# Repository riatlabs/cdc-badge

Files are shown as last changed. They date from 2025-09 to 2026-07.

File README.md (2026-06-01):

# CDC Badge

Electronic hacker badge for the [Critical Decentralization Cluster](https://decentral.community),
featuring the [TROPIC01](https://github.com/tropicsquare/tropic01) secure
element with an [ESP32-S3](https://www.espressif.com/en/products/socs/esp32-s3/) microcontroller.

Meant to be used for workshops and prototyping. It can also be worn as a mobile
badge. Features an e-paper display with frontlight, a JST connector for
single-cell LiPo batteries and a 12-button keypad.

Repository contents:
- [cdc-badge](/cdc-badge) - KiCAD project with schematics and PCB
  layout.
- [cases](/cases) - 3D printable cases.
- [docs](/docs) - Detailed documentation including datasheets and design
  decisions.
- [utils](/utils) - Miscellaneous scripts.

## Firmware
- [cdc-badge-os](https://github.com/krim404/cdc-badge-os) - Fully featured,
  modular and extensible firmware built with PlatformIO and ESP-IDF. Uses the
  TROPIC01 to build an hardware-backed key vault with support for FIDO2,
  TOTP, SSH/GPG keys and regular passwords. Also does badge functionally:
  nametag and vCard sharing.
- [xmr-cdc-badge](https://codeberg.org/telliandev/xmr-cdc-badge) - A Monero
  hardware wallet running on the CDC Badge. Built with PlatformIO.
- [cdc-badge-esphome](https://github.com/gretel/cdc-badge-esphome) - Port of
  [ESPHome](https://esphome.io). Turns the badge into a smart home device
  connected to [Home Assistant](https://www.home-assistant.io).
- [rugart](https://gitlab.com/roosemberth/rugart) - Standards-compliant PIV
  smartcard over USB CCID developed in Rust.
- [cdc-badge-nametag](https://github.com/riatlabs/cdc-badge-nametag) - Simple
  nametag with frontlight control. Built with PlatformIO.

In order to safely operate the hardware, firmware developers should take into
account all the points in the [firmware checklist](/docs/firmware-checklist.md).

The [cdc-badge-qc-firmware](https://github.com/riatlabs/cdc-badge-qc-firmware)
repo contains test batteries which make sure the hardware is working as
expected.

### Flashing
Options:
1. Via USB.
2. Via UART. TX and RX are broken out to the Raspberry Pi header on pins 8 and 10.
   The reset and flash buttons are physically placed near the ESP32.

When flashing a badge for the first time over USB you may need to press the
classic flash + reset button sequence in order to get it out of a boot loop.

## Example applications
- Interactive name tag
- Social networking games
- Monero hardware wallet
- Reticulum node with secure key storage and ECC acceleration
- FIDO2 keystore
- Pager and short message chatting
- Local AI with the Sipeed M1 HAT: e.g. voice activated control

## Expansions
The badge has 3 expansion ports:
- Raspberry Pi [40 pin GPIO header](https://pinout.xyz) ready to take any [HAT or pHAT](https://pinout.xyz/boards)
- [SAO](https://badge.team/docs/standards/sao/) ~~Shitty~~ Standardized Add-On
  port to connect small PCBs with blinky LEDs, speakers, and other bling.
- [Grove](https://wiki.seeedstudio.com/Grove_System) compatible connector to
  interface with any Grove sensor or network module. Has selectable output
  voltage (3.3 V or 5 V).

The [Grove AI HAT for Edge Computing](https://wiki.seeedstudio.com/Grove_AI_HAT_for_Edge_Computing/)
is a good pairing for more demanding applications. It is based on the [Kendryte
K210 SoC](https://www.kendryte.com/en/proDetail/210) which has 2 RISC-V 64 bit
cores and many custom accelerators (AI/NPU/CNN, audio, FFT, AES, SHA256).

### SPI to internal devices
It is possible to interface via SPI from the Raspberry Pi header to the e-paper
display and the TROPIC01. There are 2 mechanical sliding switches which you can
use to connect pin 24 and pin 26 to the chip select (CS) of these devices.

The auxiliary signals from the e-paper display (DC, RST, BUSY) are available on
pins 29, 31 and 36. The interrupt signal from TROPIC01 is available on pin 37.

This allows an external microcontroller, for instance the Sipeed M1, to display
graphics on the screen and use the secure element.

### Buttons
Besides the reset and flash buttons (directly connected to the ESP32) there are
12 buttons connected to the TCA9535 IO Expader. These can be access through I²C
and used as keypad for user input.

These is also a button (PW ON / RESET) directly connected to the BQ25895
charging IC. It has fixed functionality:
- If the BQ25895 is set to shipping mode (output power disabled), pressing the
  PW ON / RESET button for 2s disables the shipping mode and allows power to flow to the
  ESP32.
- During battery-powered operation (i.e. no charger is plugged in), pressing the
  PW ON / RESET for 12s forces a full power reset.

## Power characteristics

### Maximum
The maximum total current that can be drawn out of the power bus is:
- 3.3 V: 2 A
- 5 V: 2.5 A

Take into account that all badge components (ESP32, TROPIC01, display, etc.)
draw their power from the 3.3 V bus.

### Minimum
All onboard ICs have very low quiescent currents, under 40 μA. Even the ESP32-S3
can go as low as 8 μA in it's deep sleep mode (240 μA in light sleep mode). The
major exception is the TROPIC01 which draws 945 μA in sleep mode.

If a use case requires the lowest power usage possible, the exposed copper trace
connecting VCC to the TROPIC01 should be cut. It can later be reconnected with a
0 Ω resistor or a wire (0603 pads available). This exposed trace can also be
used to do power glitch testing on the TROPIC01.

On most use cases the sleep mode power usage of the TROPIC01 will be
insignificant though. For instance, while listening for WiFi transmissions, the
ESP32-S3 draws 95 mA. The TROPIC01 sleep mode current is just 1% of this.

## Manufacturing
There's a [Makefile](/cdc-badge/Makefile) to generate the fabrication
outputs.

To run it you need the following dependencies installed in your system:
- A Make implementation, e.g. [GNU Make](https://www.gnu.org/software/make/),
  packaged in most distros as `make`.
- [KiKit](https://yaqwsx.github.io/KiKit/latest/installation/intro/),
  packaged [in Arch as python-kikit](https://archlinux.org/packages/extra/any/python-kikit/)
  and [in NixOs as kikit](https://search.nixos.org/packages?show=kikit).

Running `make` in the `cdc-badge` directory will output the fabrication files
into the `production/` directory.

So far outputs are created just for JLCPCB, but [other manufacturers can be
easily supported](https://yaqwsx.github.io/KiKit/latest/fabrication/intro/#currently-supported).

### Panelization
Panelization is an intermediate step in the fabrication outputs generation
detailed above, but it can be run independently. `make panel` generates a 1x2
panel of the PCB into `production/panel.kicad_pcb`. This panel is the preferred
way to send the badge for fabrication. It reduces costs while preserving a rigid
structure.

## Further documentation
Please check:
- the [docs](/docs/) directory;
- the [KiCad schematics](/cdc-badge/cdc-badge.kicad_sch) (available as PDF in
  the [releases](https://github.com/riatlabs/cdc-badge/releases));

## Acknowledgments
We would like to thank:

* **ceetee**, for all the in-depth reviews, and for making us aware that we are
guiding electromagnetic waves through the dielectric and not moving water
through pipes.

* **krim**, for the tireless firmware development.

## License and authorship
Copyright © 2025-2026 RIAT Institute

Licensed under [CERN Open Hardware Licence Version 2 - Permissive](/LICENSE).

Third-party resources' authorship and license information in [AUTHORS.md](/AUTHORS.md)

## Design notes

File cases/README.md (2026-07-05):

# CDC Badge Cases

## ari
Two-part case secured by screws. Exposes screen, USB-C port, Rasp Pi header and
Grove connector. Covers SAO port.

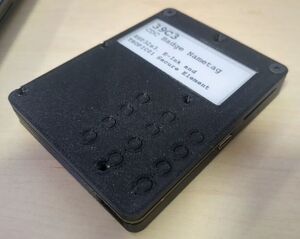
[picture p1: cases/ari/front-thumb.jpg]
front piece of ari's case

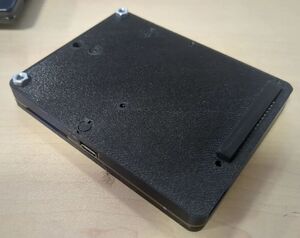
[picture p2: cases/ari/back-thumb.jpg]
back piece of ari's case


Requires:
- 2x M4 nuts
- 2x M4x15 countersunk screws
- 4x M2x15 countersunk screws (not tested, but M3 is definitely too large)
- 4x M2 nuts

Designed for printing with 2 walls with 0.6mm nozzle; 3 walls with 0.4mm nozzle
should work fine as well.

Links: [https://www.printables.com/model/1543553-cdc-badge-2-part-case](https://www.printables.com/model/1543553-cdc-badge-2-part-casel)\
Original (for CDC Badge v1.0) by [ari](https://is-a.cat/@ar).\
Adapted to v1.1 by [bobotronic](https://github.com/bobotronic).\
Licensed under [CC BY 4.0](http://creativecommons.org/licenses/by/4.0/).

## ct
Back-only case secured by clips. Exposes USB-C and SAO ports. Covers battery,
Rasp Pi header and Grove connector.

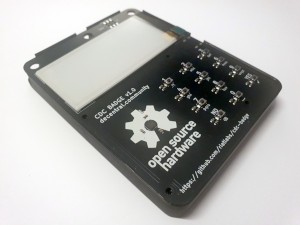
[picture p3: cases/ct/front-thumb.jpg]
front view of ct's case

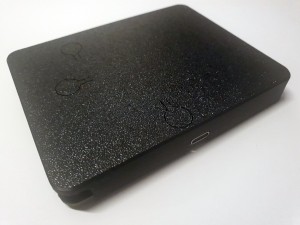
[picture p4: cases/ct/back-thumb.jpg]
back view of ct's case


Fit is close, make sure your printer can meet tolerances or add an outer wall
offset. Printing in PETG is recommended for semi flexible retention clips. PLA
works, but clips can break if you are not careful.

By [ceetee](https://github.com/its-me-ct).\
Licensed under [CERN Open Hardware Licence Version 2 - Permissive](../LICENSE).

## header-cap
A simple protective cover that fits into the Rasp Pi header and keeps the pins
from rubbing on your clothes when wearing the badge.

Two versions are available: a simple one and a beveled one. Which one fits best
depends on the particular filament that you print with. Try both versions.

By [bobotronic](https://github.com/bobotronic).\
Licensed under [CERN Open Hardware Licence Version 2 - Permissive](../LICENSE).

## Button height difference
The CDC Badge v1.0, the first production version, used [TS-1088-AR02016](https://snapeda.s3.amazonaws.com/datasheets/2304140030_XUNPU-TS-1088-AR02016_C720477.pdf)
tactile push buttons, which were found to be a bit hard to press. v1.1 and later
replaced them for [ALPS TS114516025 clones](https://www.lcsc.com/datasheet/C22375312.pdf).
These are 0.5 mm taller and thus required adjustments to the cases.

To cater for this height difference you will find the cases available in two
versions: `v1.0` and `v1.1`.

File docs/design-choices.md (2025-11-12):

# Design Choices

## Microcontroller Selection
Opted for the ESP32-S3 because of:
- USB On-The-Go (OTG) support (can act as host or peripheral).
- Onboard Bluetooth and WiFi.
- Detailed documentation available.
- Mature support in many programming languages and IDEs.
- High performance (dual-core Xtensa).
- High GPIO count.

Alternatives like the ESP32-C6 and the ESP32-C3 lack USB OTG support, have fewer
GPIOs and worse performance (single core RISC-V).

## Power Sub-System Requirements
- Lithium-ion polymer battery (LiPo)
- LiPo charging controller (nice to have: power path management, D+/D- USB detection).
- Buck converter (to 3.3V) for ESP32-S3 and header.
- Boost converter (to 5V) for header (and Sipeed M1).
- Battery gauge.

Battery protection chip and MOSFETs are unnecessary as they are integrated in
the batteries.

### Peak Power Requirements
- [ESP32-S3](https://docs.espressif.com/projects/esp-hardware-design-guidelines/en/latest/esp32s3/schematic-checklist.html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) 0.5 A × 3.3 V = 1.65 W
- [Sipeed M1](https://wiki.sipeed.com/hardware/maixface/en/core_modules/k210_core_modules.html) 1.5 W
- [TROPIC01](https://github.com/tropicsquare/tropic01/blob/main/doc/TR01-C2P-T101/ODD_TR01_datasheet_vA_10.pdf) 0.025 A × 3.3 V = 0.0825 W
- [GDEY029T94-FL03](https://www.good-display.com/product/346.html) 0.003 A (display) + 0.06 A (frontlight) × 3.3 V = 0.2079 W

Total: 3.4404 W @ 5 V ≃ 0.69 A

### LiPo
Opting for the common [PKCELL LP503562](https://www.adafruit.com/product/258)
3.7V 1200 mAh battery which comes with a 2-pin JST-PH connector.

As with other common LiPos it's voltage range is:
- full (100%): 4.2V
- mid-charge (50%): 3.7V
- low (10%): 3.3V
- depleted (0%): 3.0V

In order to slow battery degradation we will set the cut-off voltage to 3.3V.
This pairs well with our power needs. A simple buck converter will suffice to
power the ESP32-S3.

### Power Chips Selection
Opted for Texas Instruments (TI) ICs due to the detailed documentation.

#### Battery Charger
The [BQ25895](https://www.ti.com/product/BQ25895) buck battery charger was
chosen as it is the cheapest ($0.98 for 1 unit) TI chip that has power path
management and D+/D- detection alongside an Analog to Digital Converter (ADC) to
read battery voltage.\
The alternative setup consisting of the cheapest battery charger without ADC,
the [BQ24295](https://www.ti.com/product/BQ24295) ($0.67), plus the cheapest
battery gauge [BQ27220](https://www.ti.com/product/BQ27220) ($0.54) would total
$1.21 and require more passive components.

The BQ25895 is able to reverse it's operation mode, using the inductor for boost
power conversion. With this it can up the battery voltage to 5V and power
external USB devices (USB On-The-Go).\
This feature is not in use, but noted down for future reference.\
Unfortunately, as there's only one inductor, the BQ25895 cannot do buck and
boost at the same time. It is unable to supply 5V and charge the battery in
parallel.

If the BQ25895 becomes unavailable it can be easily replaced with the
[BQ25890](https://www.ti.com/product/BQ25890).

##### Inductor Selection
As per section 9.2.2.1 on BQ25895 datasheet, the minimum inductor saturation
current needed for our design is **1.38 A**. This was calculated based on:
- maximum charging current (I<sub>CHG</sub>) = 1.2 A (1C for our 1200 mAh LiPo)
- bus voltage (V<sub>BUS</sub>) = 5 V
- battery voltage (V<sub>BAT</sub>) = 3 V (the lowest we will allow is 3.3 V,
  but calculating with 3 V in case we start with a depleted battery)

One of cheapest and most available 2.2 uH inductors within this specification
turned out to be the [TECHFUSE SL0420-2R2M](https://www.lcsc.com/datasheet/C22463806.pdf).
It actually has a 5A saturation current. This affords us a big safety margin and
allows testing higher capacity LiPos.

#### 3.3V Buck Converter
A buck converter is sufficient. No need for boost as the BQ25895 keeps system
voltage always over 3.5 V by default (we will set it to 3.3 V).
Opted for the super common [TLV62569](https://www.ti.com/product/TLV62569)
adjustable buck converter which can handle 2 A.

##### Inductor Selection
As per section 8.2.2.4 off the TLV62569 datasheet, the minimum inductor
saturation current needed for our design is **2.032 A**. Calculated based on:
- V<sub>OUT</sub> = 3.3 V
- V<sub>IN</sub> = 4.2 V
- L = 2.2 µH
- f<sub>SW</sub> = 1.5 MHz
- I<sub>OUT,MAX</sub> = 2 A

We opted for SL0420-2R2M. It is within the specs and keeps our BOM small.

#### 5V Boost Converter
Opted for the [TLV61070ADBVR](https://www.ti.com/product/TLV61070A/part-details/TLV61070ADBVR)
adjustable boost converter because it can handle up to 2.5 A without an external
compensation network.

##### Inductor Selection
As per section 8.2.2.2 off the TLV61070A datasheet, the minimum inductor
saturation current needed for our design is **2.83 A**. Calculated based on:
- V<sub>OUT</sub> = 5.0 V
- V<sub>IN</sub> = 3.3 V
- L = 2.2 µH
- η = 90%
- I<sub>OUT</sub> = 1.5 A
- f<sub>SW</sub> = 1 MHz
- I<sub>LH</sub> = 0.5 A

We again opted for the SL0420-2R2M inductor.

##### Output Capacitor Selection
Per section 8.2.2.3, the minimum capacitance needed is **12 µF**. Calculated
base on the values of the previous section and:
- V<sub>RIPPLE</sub> = 0.05 V

For a I<sub>OUT</sub> of 2.5 A, the maximum current the boost converter can
handle, a **20 µF** capacitance would be needed.

We opted for 30 µF (3x 10 µF ceramic capacitors in series). This allows hackers
to reach the converter limits. It also leaves enough room for the derating of
ceramic capacitors (temperature, aging, high DC bias voltages, etc.).

#### Battery Gauge
Not needed. BQ25895 includes an ADC capable of measuring battery voltage.

### Stand-by Power Usage
All chosen ICs have very low quiescent currents, under 40 μA. Even the ESP32-S3
can go as low as 8 μA in it's deep sleep mode (240 μA in light sleep mode). The
major exception is the TROPIC01 which draws 945 μA in sleep mode. That's 90% of
all sleep mode current.

This could be addressed by connecting VCC to the TROPIC01 through a MOSFET
controlled by the ESP32. Unfortunately we have no free IO pins to implement
this.

If a use case requires the lowest power usage possible, the exposed copper trace
connecting VCC to the TROPIC01 should be cut. It can later be reconnected with a
0 Ω resistor or a wire (0603 pads available). This exposed trace can also be
used to do power glitch testing on the TROPIC01.

On most use cases the sleep mode power usage of the TROPIC01 will be
insignificant though. For instance, while just listening for WiFi transmissions,
the ESP32-S3 draws 95 mA. The TROPIC01 sleep mode current is just 1% of this.

## Keypad and I/O Expander
The badge needs a 12-button keypad (0-9, yes, no) for PIN input into the
TROPIC01. In order to streamline production we opted for 12 SMD tactile push
buttons, which is also both cheaper and smaller than adding an external keypad.

Our ESP32-S3 lacks enough IO pins to connect these 12 buttons plus all the other
IOs from the chips and headers on the badge. Applying XY multiplexing or even
Charlieplexing would not solve it. We thus opted for an I²C I/O Expander, the
[TCA9535](https://www.ti.com/lit/ds/symlink/tca9535.pdf). It has 16 IOs, enough
to connect all buttons individually and avoid the complexities of multiplexing
(expanders with lower pin count are not meaningfully cheaper).

### Debouncing
Opted for hardware debouncing to ease software development and avoid busy
waits. Using a basic circuit composed of a capacitor in parallel with each
keypad button (alongside its pull-up resistor). This [only debounces the rising
edge](https://www.ti.com/video/5840441551001) (switch opened). There's no
debouncing when the switch is closed (falling edge). This is acceptable as we
are just interested in switch activation. A [more complex RC network](https://www.digikey.com/en/articles/how-to-implement-hardware-debounce-for-switches-and-relays)
can be implemented if switch deactivation becomes relevant.

Using 4.7 kΩ resistor and 100 nF capacitor. RC time constant is thus 4.7 ms.
The tactile push buttons we are using should have a bounce duration of 1 ms,
which is well within this RC time.

## I²C Buses
The badge makes full use of the two I²C buses on the ESP32-S3:
- bus 0 connects the ESP32 to the on-board chips: charging IC and IO expander.\
  Operates in standard mode (100 kbit/s) as both chips are low bandwidth.
- bus 1 is broken out to the Raspberry Pi header and to the SAO port.\
  Prepared to operate in fast mode (400 kbit/s), the ESP32-S3 maximum.

### Pull-up Resistors
Per equation (1) on [SLVA689](https://www.ti.com/lit/an/slva689/slva689.pdf) the
minimum pull-up resistance should be 966 Ω.\
Calculated based on:
- V<sub>CC</sub> = 3.3 V
- V<sub>OL(max)</sub> = 0.4 V
- I<sub>OL</sub> = 3 mA

#### Bus 0
With equation (6) we get a maximum pull-up resistance of 118 kΩ.\
Based on:
- tr = 1000 ns (standard mode)
- C<sub>b</sub> = 2 pF (ESP32-S3 inputs) + 3 pF (TCA9535) + 3 pF (BQ25895,
guessed) + 2 pF (10 cm [PCB trace](https://voltage-drop-calculator.com/pcb-trace-capacitance-calculator.php))
= 10 pF

A conservative value of **10 kΩ** was chosen as it's power consumption is low
enough (0.33 mA).

#### Bus 1
With the same equation (6) we get a maximum pull-up resistance of 29.5 kΩ.\
Based on:
- tr = 300 ns (fast mode)
- C<sub>b</sub> = 2 pF (ESP32) + 3 pF (hypothetical target) + 7 pF (hypothetical
15 cm long [24 AWG cable](https://www.weicowire.com/24-awg-1751.html)) = 12 pF

**10 kΩ** was also chosen as a safe value. If needed, the target device can
lower the resistance by connecting another pull-up resistor in parallel.

## Grove
The Grove connector's pins 1 and 2 are wired to the ESP32-S3 IO1 and IO2. These
ESP32 pins can double as analog or digital IOs, and thus provide all the
flexibility needed by the Grove connector. Under the [Grove
specification](https://wiki.seeedstudio.com/Grove_System/#interface-of-grove-modules)
these pins should work as either digital IOs, analog IOs, or even as UART or I²C
communication pins.\
For I²C usage the pull-up resistors must be provided by the peripheral
connecting to the badge, or soldered into the 0603 pads left unpopulated for
this purpose.

The [Grove connector is
proprietary](https://arduino.stackexchange.com/questions/9030/what-type-of-connector-does-the-grove-system-use)
and difficult to source anywhere outside of Seed Studio stores. We are
therefore experimenting with the [Boom Precision Electronics
HY-4P](https://jlcpcb.com/partdetail/C146060) as a replacement.

## SAO port
As per ["standard"](https://hackaday.io/project/52950-shitty-add-ons/log/159806-introducing-the-shitty-add-on-v169bis-standard)
we use a 2x3 female header with 2.54 mm pitch. But opted for a header with
bottom entry. This allows the header to be soldered on the badge side that faces
the user's body, while the add-ons connect from the outer side and can show
their bling to the world.\
This keeps the badge as thin as possible, with all tall parts (SAO port,
Raspberry Pi header, battery) on the same side. It also prevents the add-ons
from acting as levers that could rip-off the SAO port from the PCB (note that we
are using a surface mounted header).

## E-Paper Display
Opted for the Good Display [GDEY029T94-FL03](https://www.good-display.com/product/346.html)
which comes bonded with a frontlight (nice for the low light environments at
hacker's events). This display is readily available and has good documentation
and driver libraries.

### Frontlight LED driver
Lab tests with no current limit:

Voltage | Current | Perceived brightness
------: | ------: | --------------------
  2.4 V | 0.000 A | no light
  2.5 V | 0.000 A | dim light
  2.6 V | 0.005 A | nice light
  2.7 V | 0.017 A | getting too much
  2.8 V | 0.033 A | no need for this all
  2.9 V | 0.050 A | noticeable increase
  3.0 V | 0.067 A | no need to go over this
  3.1 V | 0.086 A | brightness increase is small
  3.2 V | 0.109 A | increase barely perceivable
  3.3 V | 0.133 A | practically the same as previous

Opting for **3.0 V** as maximum allowed voltage. Enforced with a current
limiting resistor (5.1 Ω). This keeps the forward current close to the typical
value (60 mA) listed in the datasheet.

Using the ESP32-S3 LED PWM controller to adjust brightness. Amplification is
needed as the maximum current output on the S3 pins cannot exceed 40 mA. Opted
to drive the frontlight through a Si1308EDL MOSFET as we already had one in our
BOM.

## USB On-The-Go
Currently unsupported.

The ESP32-S3 has [poorly documented](https://danielmangum.com/posts/usb-otg-esp32s3/)
USB On-The-Go (OTG) functionally.

The current badge design uses fixed 5.1 kΩ resistors pulling the USB-C CC1 and
CC2 pins down to ground. This makes the badge always appear as a USB device, aka
upstream-facing port (UFP), to other devices connected via USB-C. In other to
have it appear as a USB host, aka downstream-facing port (DFP),
[a different resistor configuration](https://electronics.stackexchange.com/a/588163/307867)
would be required.

Such resistor configuration change would have to be handled by the ESP32
alongside configuring the battery charging IC to work as a power source
(boost/OTG mode). A proper bulk capacitor would have to be added to the charging
IC PMID pin.

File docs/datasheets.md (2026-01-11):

# Datasheets
Links to the datasheets of the components used in the CDC Badge.
All archived at: https://archive.org/details/cdc-badge-datasheets

Microcontroller: ESP32-S3-WROOM-1\
https://www.espressif.com/sites/default/files/documentation/esp32-s3-wroom-1_wroom-1u_datasheet_en.pdf
https://www.espressif.com/sites/default/files/documentation/esp32-s3_datasheet_en.pdf
https://www.espressif.com/sites/default/files/documentation/esp32-s3_technical_reference_manual_en.pdf

E-paper Display: GDEY029T94-FL03\
https://v4.cecdn.yun300.cn/100001_1909185148/GDEY029T94-FL03.pdf

Display Connector (FFC / FPC 24P top contact slide lock 0.5 mm): AFC07-S24ECA-00\
https://www.lcsc.com/datasheet/C262643.pdf

Frontlight Connector (FFC / FPC 6P bottom contact slide lock 0.5 mm): AFC07-S06FCA-00\
https://www.lcsc.com/datasheet/C262553.pdf

Charging IC: BQ25895\
http://www.ti.com/lit/ds/symlink/bq25895.pdf

Thermistor (10kΩ NTC, 3435K B-value at 25 ℃  and 85 ℃ ): B57332V5103F360\
https://product.tdk.com/system/files/dam/doc/product/sensor/ntc/chip-ntc-thermistor/data_sheet/50/db/ntc/ntc_smd_automotive_series_0402-0805.pdf

Buck Converter: TLV62569\
http://www.ti.com/lit/ds/symlink/tlv62569.pdf

Boost Converter: TLV61070A\
https://www.ti.com/lit/ds/symlink/tlv61070a.pdf

Inductor (2.2 μH): SL0420-2R2M\
https://www.lcsc.com/datasheet/C22463806.pdf

Inductor (47 μH): FNR4030S470MT\
https://www.lcsc.com/datasheet/C167888.pdf

Battery (LiPo 1200 mAh): LP503562\
https://www.batterypkcell.com/uploads/LP503562-1200mAh-3.7V-AD306055-20230615.pdf

Battery Connector: S2B-PH-SM4-TB\
https://www.jst-connector.com/datasheet/jst-connector/S2B-PH-SM4-TB(LF)(SN).pdf

IO Expander: TCA9535\
http://www.ti.com/lit/ds/symlink/tca9535.pdf

Tactile push button: TS114516025\
https://www.lcsc.com/datasheet/C22375312.pdf

Single pole double throw sliding switch: MST-22D18G2 3J\
https://www.lcsc.com/datasheet/C668586.pdf

USB-C Receptacle: Shouhan TYPE-C 16PIN 2MD (073)\
https://snapeda.s3.amazonaws.com/datasheet/2111231930_SHOU-HAN-TYPE-C-16PIN-2MD-073_C2765186.pdf

TVS diode (14V): SMF14CA\
https://www.lcsc.com/datasheet/lcsc_datasheet_2409201747_hongjiacheng-SMF14CA_C41411783.pdf

TVS diode (3.3V): H3V3U06B\
https://www.lcsc.com/datasheet/C20617908.pdf

Secure Element: TR01-C2P-T301\
https://github.com/tropicsquare/tropic01/blob/main/doc/TR01-C2P-T301/ODD_TR01_datasheet_vA_10.pdf

MOSFET: Si1308EDL\
https://www.lcsc.com/datasheet/C7603347.pdf

Diode: MBR0530T1G\
https://www.onsemi.com/download/data-sheet/pdf/mbr0530t1-d.pdf

SAO Port (2x3 2.54mm female header): HC-PM254-8.5H-2x3PS\
https://www.lcsc.com/datasheet/C22373944.pdf

Grove Connector: HY-4P (A2006WF-04A)\
https://www.lcsc.com/datasheet/C146060.pdf

Raspberry Pi Header (2x20 2.54 mm male header): HB-PH9-254220PB2GOW\
https://www.lcsc.com/datasheet/C42396895.pdf

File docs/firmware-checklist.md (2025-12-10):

# Firmware Checklist
If you are writing firmware for the CDC Badge you should make sure to cater for
the following settings on every boot. Remember that the auxiliary ICs on the
badge do not have persistent memory.

## Lower fast charge current
Set the fast charge current limit on the charging chip (BQ25895) to a value
bellow 1200 mA. I²C register REG04[0-6]. Recommended value: 512 mA.

The BQ25895 default fast charge current is 2048 mA, which would damage the 1200
mAh LiPo battery bundled with the badge.

## Lower minimum system voltage
Set the minimum system voltage to 3.3 V on REG03[1-3] of the BQ25895.

By default the BQ25895 regulates system voltage to be always over 3.5 V even
when the LiPo falls bellow this. However CDC Badge is designed to work with
voltages down to 3.3 V, allowing more efficient power usage.

## Get away from the USB bus during charging port detection
Watch the CHG_DSEL pin (IO21). When active (low) disable the USB data pins
(IO19 and IO20), e.g., set them to input/high-z. USB communication can be
resumed when CHG_IRQ (IO39) gets triggered (also active on low). Read section
8.2.3.3 of the [BQ25895 datasheet](http://www.ti.com/lit/ds/symlink/bq25895.pdf)
for further details.

If this is not taken this into account the USB charging port detection will
fail and/or conflict with other ongoing communication on the USB bus.

Another approach is disabling USB charging port detection on the BQ25895
(REG02[0]). This comes at the expense of slower charging, which is ok if only
500 mA @ 5V are needed (the USB 2.0 default).

## Watch charging IC interrupts and read status
Watch out for interrupts triggered by the BQ25895 on the CHG_IRQ pin (IO39) and
read it's status and voltage registers to understand what happened.

Registers: REG0B, REG0C, REG0E, REG0F, REG10, REG11, REG12 and REG13.

## Implement full system power off
Power off system by enabling shipping mode on REG09[5] of the BQ25895.
This can be triggered after a long press of the flash button (IO0).

To boot back the system the user will have to press the PW ON / RESET button for
2 seconds.

## Put TROPIC01 into sleep mode
Put the secure element into sleep mode when not used in order to reduce power
usage.

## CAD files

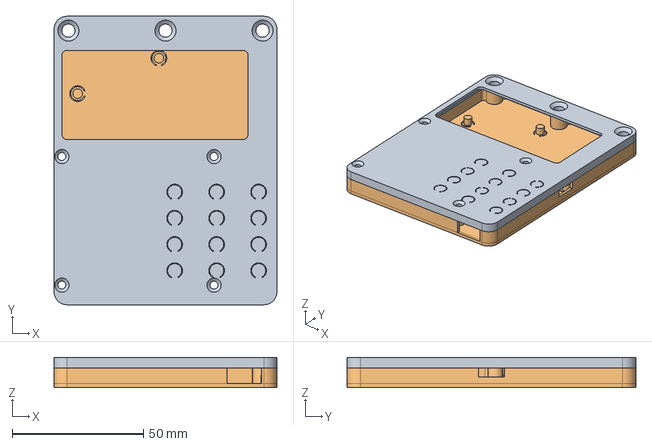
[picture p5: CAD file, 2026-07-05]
cases/ari/v1.1/all.FCStd
85.0 x 110.0 x 11.5 mm
front
back

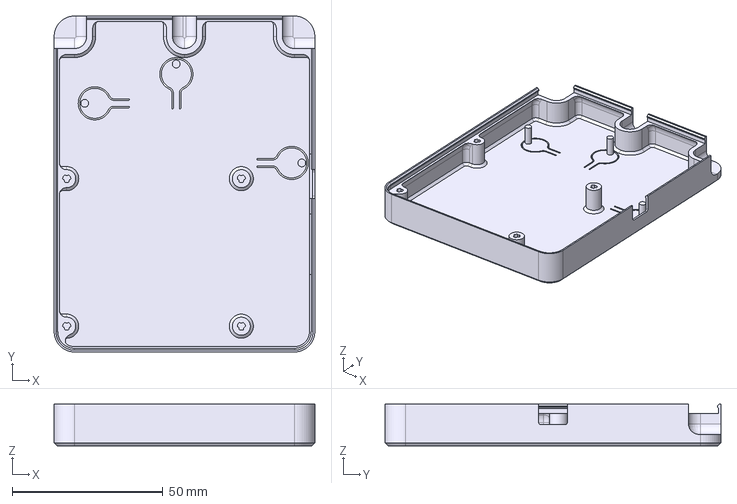
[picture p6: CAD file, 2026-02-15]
cases/ct/v1.1/back.step
86.6 x 111.6 x 13.8 mm

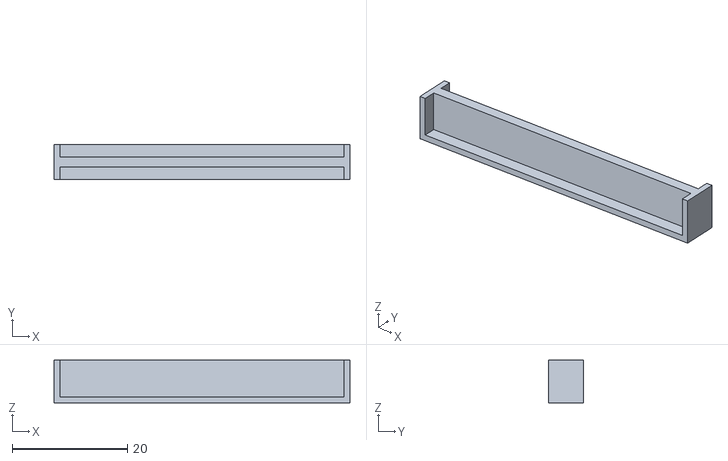
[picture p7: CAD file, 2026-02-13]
cases/header-cap/simple.stl
51.4 x 6.00 x 7.39

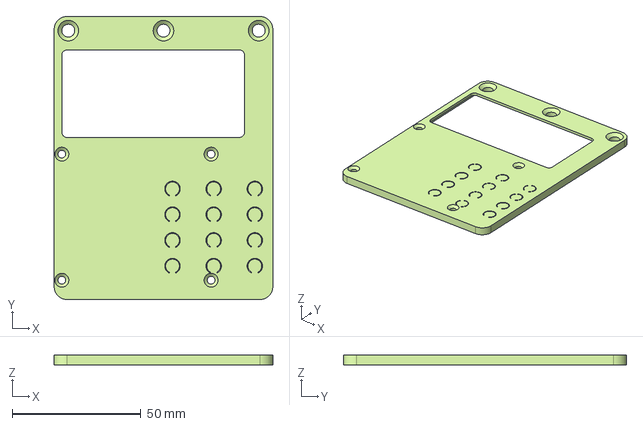
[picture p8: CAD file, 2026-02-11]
cases/ari/v1.1/front.step
85.0 x 110.0 x 3.70 mm

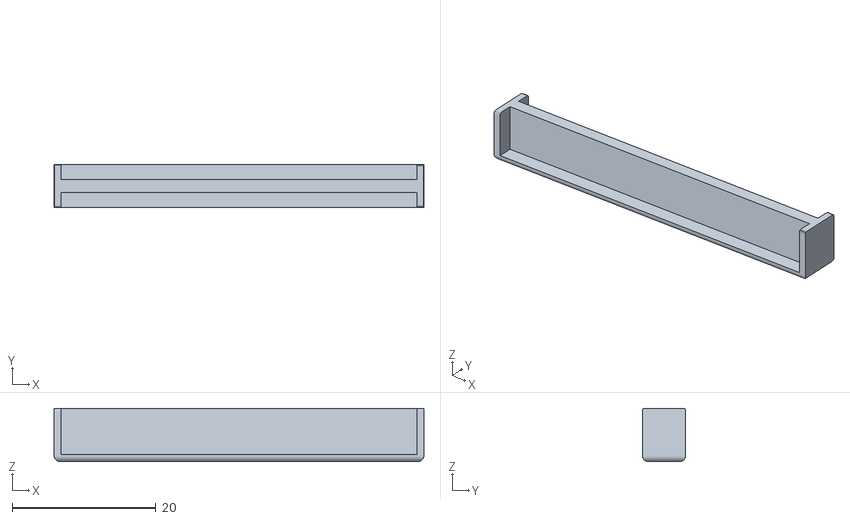
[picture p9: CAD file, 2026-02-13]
cases/header-cap/beveled.stl
51.4 x 6.00 x 7.39

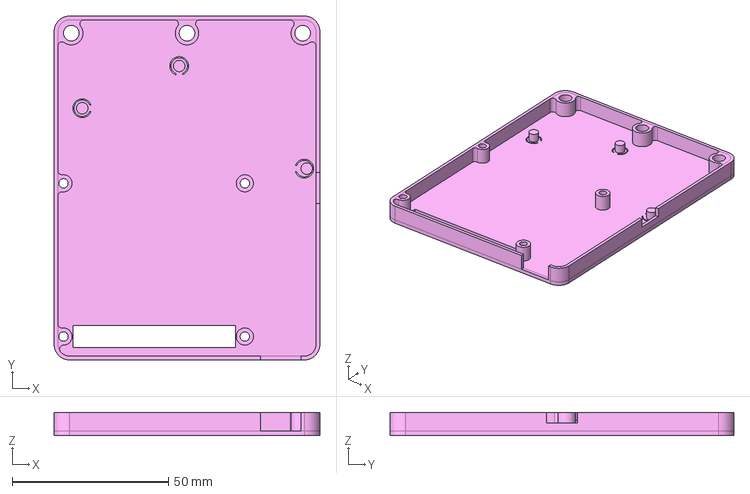
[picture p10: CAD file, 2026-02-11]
cases/ari/v1.1/back.step
85.0 x 110.0 x 7.50 mm

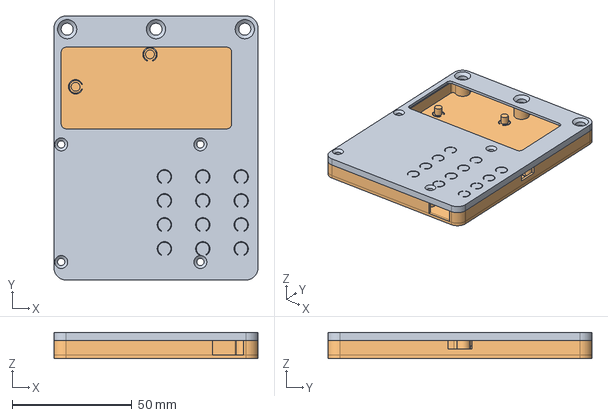
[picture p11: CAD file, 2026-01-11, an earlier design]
cases/ari/v1.0/all.FCStd
85.0 x 110.0 x 11.0 mm
front
back

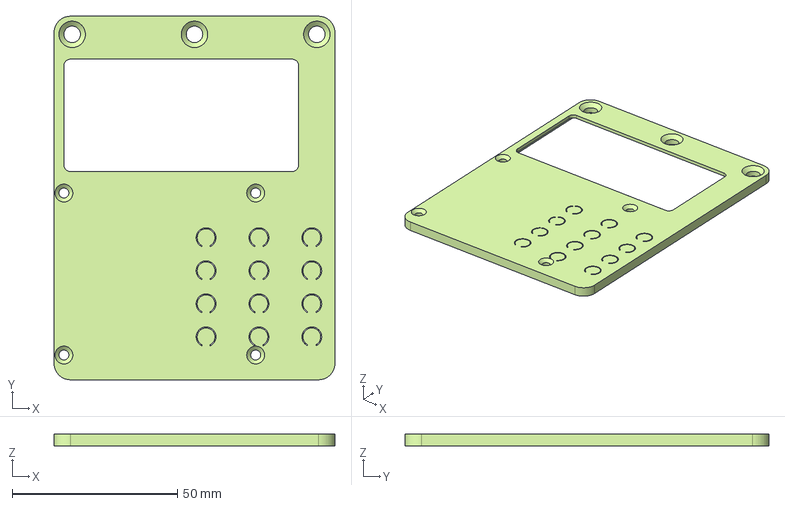
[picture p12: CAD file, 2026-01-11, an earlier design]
cases/ari/v1.0/front.step
85.0 x 110.0 x 3.50 mm

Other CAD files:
cases/ct/v1.0/back.step
cases/ari/v1.0/back.step
cases/header-cap/beveled.blend
cases/header-cap/simple.blend

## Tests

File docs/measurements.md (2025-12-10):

# Measurements

## v0.1

### 3.3V rail
Always perfect (has load always).

### 5V rail
#### No load
id | rail V
-- | ------
 0 |  5.153
 1 |  5.188
 2 |  5.114
 3 |  5.149

#### 0.5A load
id | rail V
-- | ------
 0 |  5.006
 1 |  5.009
 2 |  4.985
 3 |  4.992

### Charge voltage and current
With default settings on the BQ25895.

If the ESP32-S3 is on, only the USB 2.0 default (5V, 0.5A) gets activated.

If the ESP32-S3 is off (EN/RESET button continuously pressed) the BQ25895 is
able to negotiate higher power modes. It can get 12V (tested with a Baseus GaN
Pro) and charges the battery at 1 A.

Conclusion: S3 firmware must watch the DSEL pin and get out of the USB bus while
power negotiation is going on.

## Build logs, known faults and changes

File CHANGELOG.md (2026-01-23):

# Changelog

## v1.1
Jan 23, 2026\
Second mass produced version, sent to JLCPCB.

- Push buttons with larger keycap and better tactile feedback.
- New front side graphic design: OSHW logo inspired mesh network.

## v1.0
Dec 11, 2025\
Mass produced version, sent to JLCPCB.

- Place flash and enable buttons far apart for easier clicking.
- Detailed silkscreen labeling of IO pins and buttons.
- Enlarge flex cable cut-out and make edges rounder.
- New front side silkscreen graphic design, featuring the OSHW logo.
- Move Grove connector 1mm left, making absolutely sure all HATs fit.

## v0.1
Nov 25, 2025\
Test run, produced in JLCPCB.

- Includes all planned components and features.

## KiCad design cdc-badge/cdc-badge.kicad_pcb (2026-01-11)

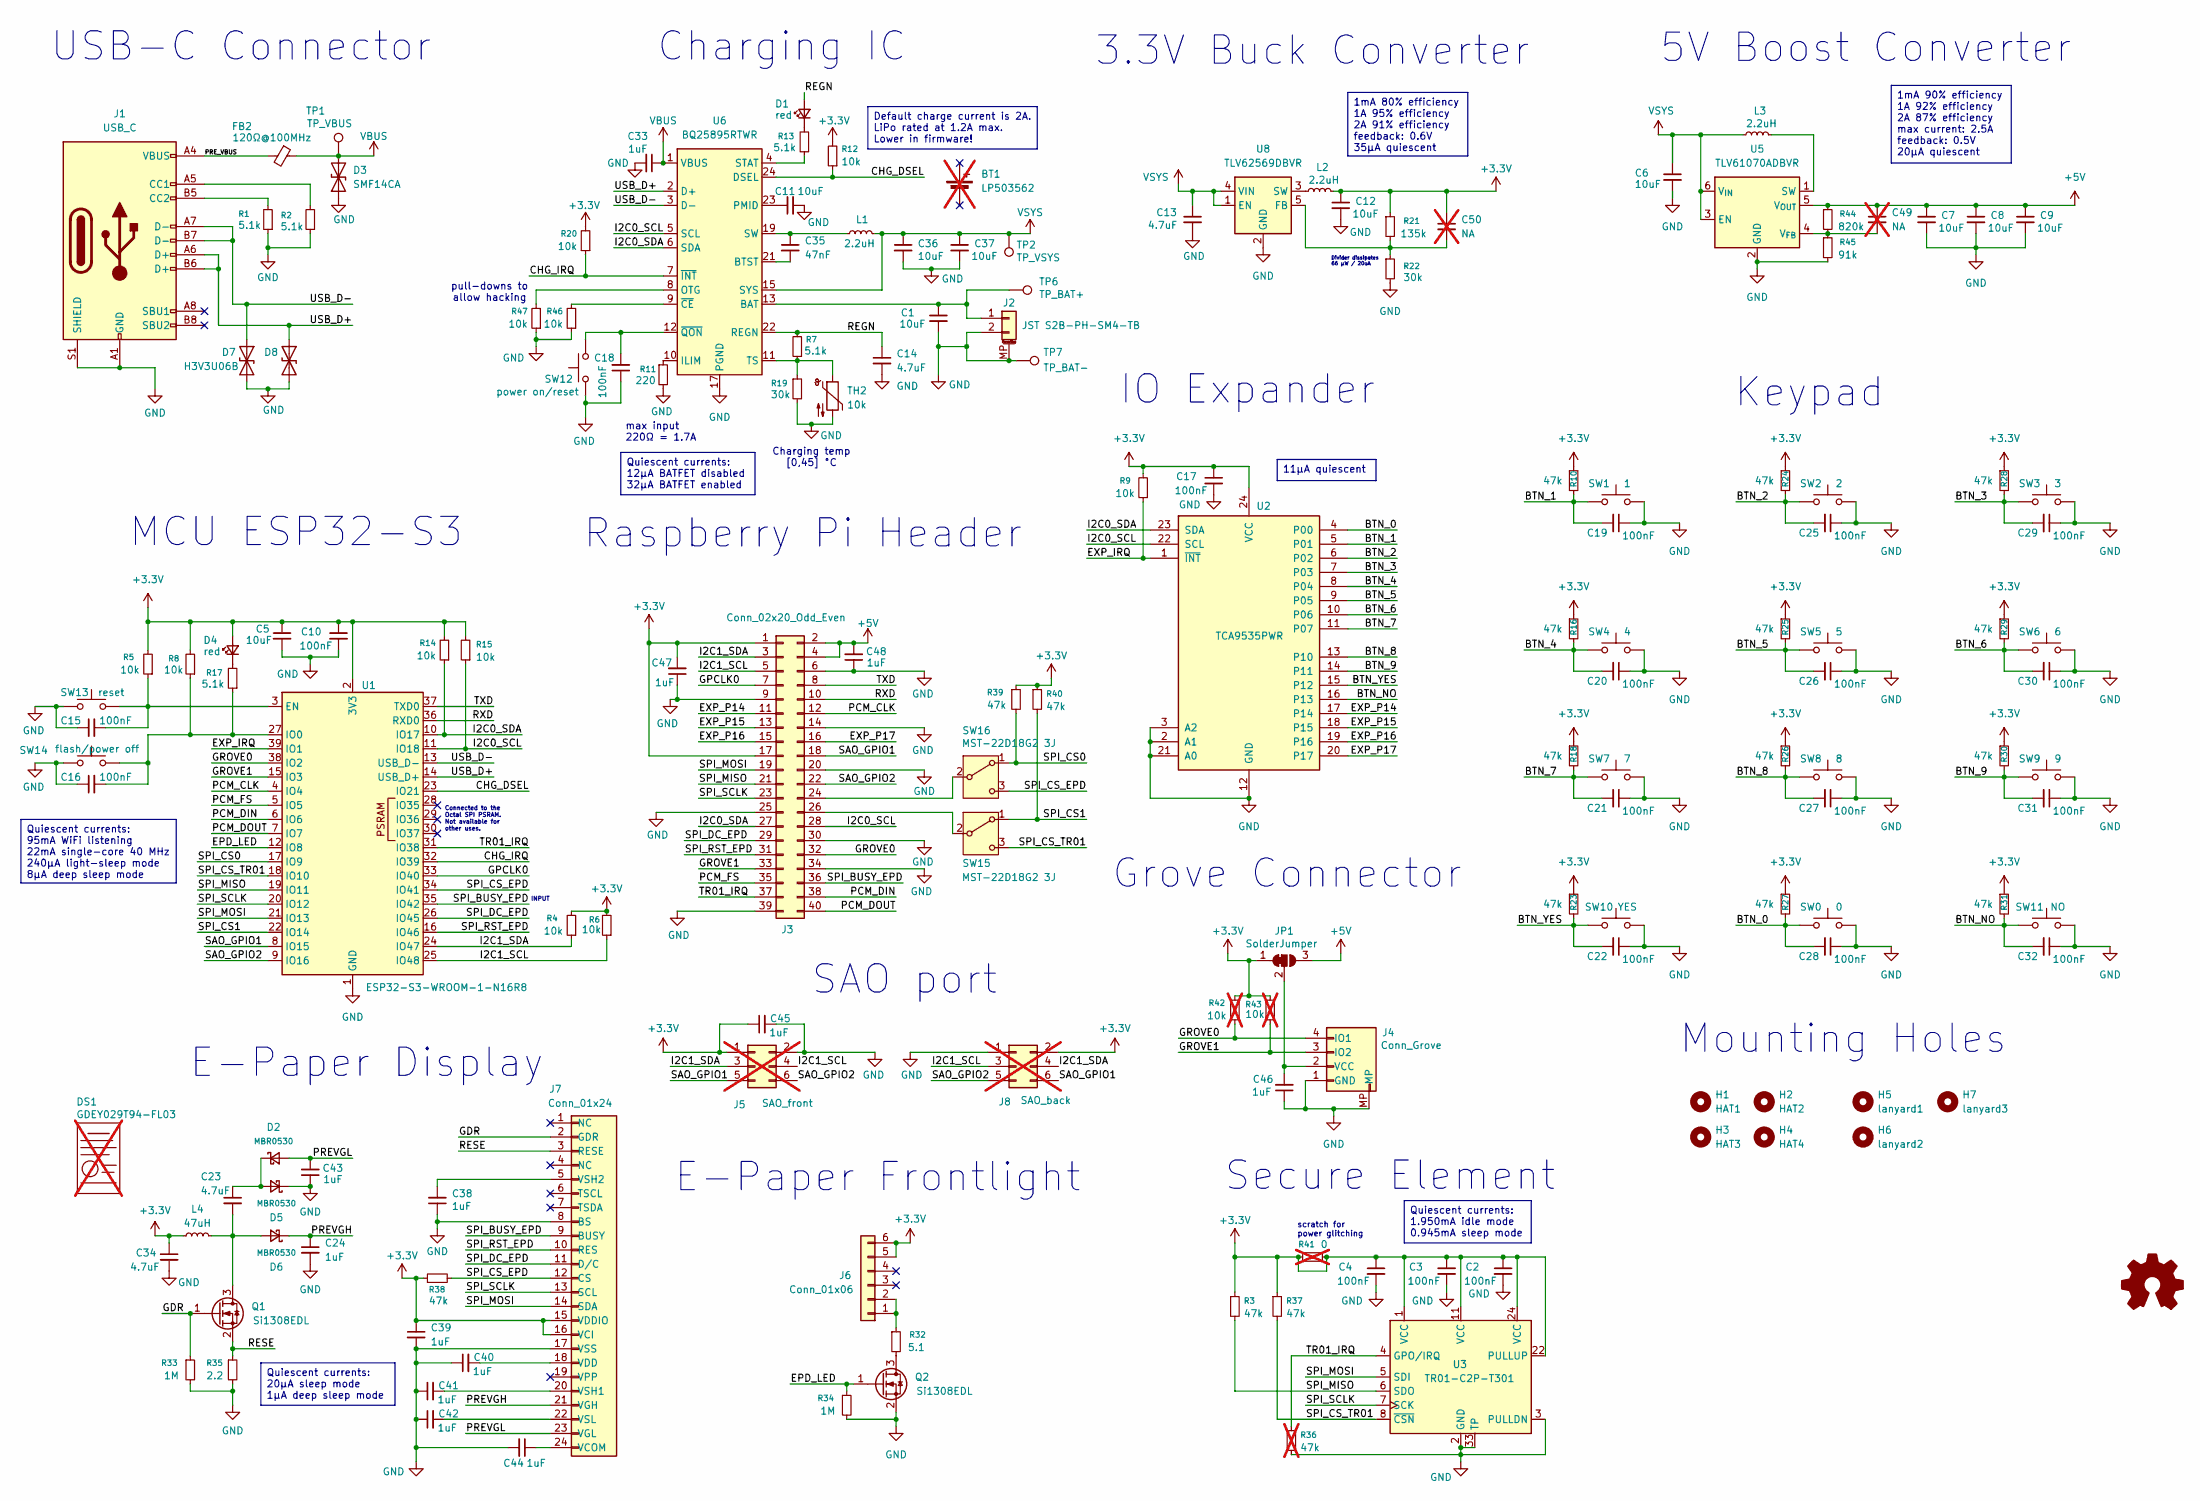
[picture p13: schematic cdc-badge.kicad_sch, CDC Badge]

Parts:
BT1: LP503562; PKCELL_LP503562_invert; not fitted
C1, C5, C6, C7, C8, C9, C11, C12, C36, C37: 10uF; C_0805_2012Metric; MPN CL21A106KAYNNNE; JLCPCB PN C15850
C2, C3, C4, C10, C15, C16, C17, C18, C19, C20, C21, C22, C25, C26, C27, C28, C29, C30, C31, C32: 100nF; C_0603_1608Metric; MPN CC0603KRX7R9BB104; JLCPCB PN C14663
C13, C14, C23, C34: 4.7uF; C_0805_2012Metric; MPN CL21A475KAQNNNE; JLCPCB PN C1779
C24, C33, C38, C39, C40, C41, C42, C43, C44, C45, C46, C47, C48: 1uF; C_0603_1608Metric; MPN CL10A105KB8NNNC; JLCPCB PN C15849
C35: 47nF; C_0603_1608Metric; MPN CL10B473KB8NNNC; JLCPCB PN C1622
C49, C50: NA; C_0603_1608Metric; not fitted
D1, D4: red; LED_0603_1608Metric; MPN KT-0603R; JLCPCB PN C2286
D2, D5, D6: MBR0530; D_SOD-123; MPN MBR0530T1G; JLCPCB PN C82046
D3: SMF14CA; D_SOD-123FL_Unpolarized; MPN SMF14CA; JLCPCB PN C41411783
D7, D8: H3V3U06B; D_DFN0603-2L_Unpolarized; MPN H3V3U06B; JLCPCB PN C20617908
DS1: GDEY029T94-FL03; not fitted
FB2: 120Ω@100MHz; L_0805_2012Metric; MPN HCB2012KF-121T50; JLCPCB PN C304323
H1: HAT1; MountingHole_2.7mm_KeepOut
H2: HAT2; MountingHole_2.7mm_KeepOut
H3: HAT3; MountingHole_2.7mm_KeepOut
H4: HAT4; MountingHole_2.7mm_KeepOut
H5: lanyard1; MountingHole_5.5mm
H6: lanyard2; MountingHole_5.5mm
H7: lanyard3; MountingHole_5.5mm
J1: USB_C; SHOUHAN_TYPE-C_16PIN_2MD_073; MPN TYPE-C 16PIN 2MD(073); JLCPCB PN C2765186
J2: JST S2B-PH-SM4-TB; JST_PH_S2B-PH-SM4-TB_1x02-1MP_P2.00mm_Horizontal; JLCPCB PN C295747
J3: Conn_02x20_Odd_Even; PinHeader_2x20_P2.54mm_Vertical_SMD; MPN HB-PH9-254220PB2GOW; JLCPCB PN C42396895
J4: Conn_Grove; BOOMELE_HY-4P_1x04-1MP_P2mm_Horizontal; MPN HC-HY-4AWT; JLCPCB PN C146060
J5: SAO_front; Wuerth_WR-PHD_610006243021_SMD_2x03_P2.54mm_Vertical; MPN 610006243021; not fitted
J6: Conn_01x06; Jushuo_AFC07-S06FCA-00_1x6-1MP_P0.50_Horizontal; MPN AFC07-S06FCA-00; JLCPCB PN C262553
J7: Conn_01x24; Jushuo_AFC07-S24ECA-00_1x24-1MP_P0.50_Horizontal; MPN AFC07-S24ECA-00; JLCPCB PN C262643
J8: SAO_back; Wuerth_WR-PHD_610006243021_SMD_2x03_P2.54mm_Vertical; MPN 610006243021; not fitted
JP1: SolderJumper; SolderJumper-3_P1.3mm_Bridged12_RoundedPad1.0x1.5mm
L1, L2, L3: 2.2uH; L_TechFuse_SL0420; MPN SL0420-2R2M; JLCPCB PN C22463806
L4: 47uH; L_Changjiang_FNR4030S; MPN FNR4030S470MT; JLCPCB PN C167888
Q1, Q2: Si1308EDL; SOT-323_SC-70; MPN SI1308EDL; JLCPCB PN C7603347
R1, R2, R7, R13, R17: 5.1k; R_0603_1608Metric; MPN 0603WAF5101T5E; JLCPCB PN C23186
R3, R10, R16, R18, R23, R24, R25, R26, R27, R28, R29, R30, R31, R37, R38, R39, R40: 47k; R_0603_1608Metric; MPN 0603WAF4702T5E; JLCPCB PN C25819
R4, R5, R6, R8, R9, R12, R14, R15, R20, R46, R47: 10k; R_0603_1608Metric; MPN 0603WAF1002T5E; JLCPCB PN C25804
R11: 220; R_0603_1608Metric; MPN 0603WAF2200T5E; JLCPCB PN C22962
R19, R22: 30k; R_0603_1608Metric; MPN 0603WAF3002T5E; JLCPCB PN C22984
R21: 135k; R_0603_1608Metric; MPN RT0603BRD07135KL; JLCPCB PN C861113
R32: 5.1; R_0603_1608Metric; MPN 0603WAF510KT5E; JLCPCB PN C25197
R33, R34: 1M; R_0603_1608Metric; MPN 0603WAF1004T5E; JLCPCB PN C22935
R35: 2.2; R_0603_1608Metric; MPN 0603WAF220KT5E; JLCPCB PN C22939
R36: 47k; R_0603_1608Metric; MPN 0603WAF4702T5E; JLCPCB PN C25819; not fitted
R41: 0; R_0603_1608Metric; MPN 0603WAF0000T5E; JLCPCB PN C21189; not fitted
R42, R43: 10k; R_0603_1608Metric; MPN 0603WAF1002T5E; JLCPCB PN C25804; not fitted
R44: 820k; R_0603_1608Metric; MPN RC0603FR-07820KL; JLCPCB PN C141684
R45: 91k; R_0603_1608Metric; MPN 0603WAF9102T5E; JLCPCB PN C23265
SW0: 0; SW_Push_1P1T_NO_TS1145x; MPN TS114516025; JLCPCB PN C22375312
SW1: 1; SW_Push_1P1T_NO_TS1145x; MPN TS114516025; JLCPCB PN C22375312
SW2: 2; SW_Push_1P1T_NO_TS1145x; MPN TS114516025; JLCPCB PN C22375312
SW3: 3; SW_Push_1P1T_NO_TS1145x; MPN TS114516025; JLCPCB PN C22375312
SW4: 4; SW_Push_1P1T_NO_TS1145x; MPN TS114516025; JLCPCB PN C22375312
SW5: 5; SW_Push_1P1T_NO_TS1145x; MPN TS114516025; JLCPCB PN C22375312
SW6: 6; SW_Push_1P1T_NO_TS1145x; MPN TS114516025; JLCPCB PN C22375312
SW7: 7; SW_Push_1P1T_NO_TS1145x; MPN TS114516025; JLCPCB PN C22375312
SW8: 8; SW_Push_1P1T_NO_TS1145x; MPN TS114516025; JLCPCB PN C22375312
SW9: 9; SW_Push_1P1T_NO_TS1145x; MPN TS114516025; JLCPCB PN C22375312
SW10: YES; SW_Push_1P1T_NO_TS1145x; MPN TS114516025; JLCPCB PN C22375312
SW11: NO; SW_Push_1P1T_NO_TS1145x; MPN TS114516025; JLCPCB PN C22375312
SW12: power on/reset; SW_Push_1P1T_NO_TS1145x; MPN TS114516025; JLCPCB PN C22375312
SW13: reset; SW_Push_1P1T_NO_TS1145x; MPN TS114516025; JLCPCB PN C22375312
SW14: flash/power off; SW_Push_1P1T_NO_TS1145x; MPN TS114516025; JLCPCB PN C22375312
SW15, SW16: MST-22D18G2 3J; SW_SPDT_Shouhan_MST-22D18G2_3J; MPN MST-22D18G2 3J; JLCPCB PN C2875122
TH2: 10k; R_0603_1608Metric; MPN B57332V5103F360; JLCPCB PN C209893
TP1: TP_VBUS; TestPoint_Pad_D2.0mm
TP2: TP_VSYS; TestPoint_Pad_D2.0mm
TP6: TP_BAT+; TestPoint_Pad_D2.0mm
TP7: TP_BAT-; TestPoint_Pad_D2.0mm
U1: ESP32-S3-WROOM-1-N16R8; ESP32-S3-WROOM-1; MPN ESP32-S3-WROOM-1-N16R8; JLCPCB PN C2913202
U2: TCA9535PWR; TSSOP-24_4.4x7.8mm_P0.65mm; MPN TCA9535PWR; JLCPCB PN C130204
U3: TR01-C2P-T301; QFN-32-1EP_4x4mm_P0.4mm_EP2.9x2.9mm; JLCPCB PN C9900235223
U5: TLV61070ADBVR; SOT-23-6; MPN TLV61070ADBVR; JLCPCB PN C6881375
U6: BQ25895RTWR; Texas_RTW_WQFN-24-1EP_4x4mm_P0.5mm_EP2.7x2.7mm_0.3mmThermal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; MPN BQ25895RTWR; JLCPCB PN C80200
U8: TLV62569DBVR; SOT-23-5; MPN TLV62569DBVR; JLCPCB PN C141836

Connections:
+3.3V: C2.1, C3.1, C4.1, C5.1, C10.1, C12.1, C17.1, C34.1, C39.1, C45.1, C47.2, C50.1, D4.2 (A), J3.1, J3.17, J5.1, J6.5, J6.6, J7.15 (VDDIO), J7.16 (VCI), J8.2, JP1.1 (A), L2.2, L4.1, R3.1, R4.2, R5.2, R6.2, R8.2, R9.2, R10.1, R12.2, R14.2, R15.2, R16.1, R18.1, R20.2, R21.1, R23.1, R24.1, R25.1, R26.1, R27.1, R28.1, R29.1, R30.1, R31.1, R37.1, R38.1, R39.1, R40.1, R41.1, R41.2, R42.2, R43.2, U1.2 (3V3), U2.24 (VCC), U3.1 (VCC), U3.11 (VCC), U3.22 (PULLUP), U3.24 (VCC)
+5V: C7.1, C8.1, C9.1, C48.2, C49.1, J3.2, J3.4, JP1.3 (B), R44.1, U5.5 (V_{OUT})
/BTN_0: C28.2, R27.2, SW0.1, U2.4 (P00)
/BTN_1: C19.2, R10.2, SW1.1, U2.5 (P01)
/BTN_2: C25.2, R24.2, SW2.1, U2.6 (P02)
/BTN_3: C29.2, R28.2, SW3.1, U2.7 (P03)
/BTN_4: C20.2, R16.2, SW4.1, U2.8 (P04)
/BTN_5: C26.2, R25.2, SW5.1, U2.9 (P05)
/BTN_6: C30.2, R29.2, SW6.1, U2.10 (P06)
/BTN_7: C21.2, R18.2, SW7.1, U2.11 (P07)
/BTN_8: C27.2, R26.2, SW8.1, U2.13 (P10)
/BTN_9: C31.2, R30.2, SW9.1, U2.14 (P11)
/BTN_NO: C32.2, R31.2, SW11.1, U2.16 (P13)
/BTN_YES: C22.2, R23.2, SW10.1, U2.15 (P12)
/CHG_DSEL: R12.1, U1.23 (IO21), U6.24 (DSEL)
/CHG_IRQ: R20.1, U1.32 (IO39), U6.7 (~INT)
/EPD_LED: Q2.1 (G), R34.1, U1.12 (IO8)
/EXP_IRQ: R9.1, U1.39 (IO1), U2.1 (~INT)
/EXP_P14: J3.11, U2.17 (P14)
/EXP_P15: J3.13, U2.18 (P15)
/EXP_P16: J3.15, U2.19 (P16)
/EXP_P17: J3.16, U2.20 (P17)
/GDR: J7.2 (GDR), Q1.1 (G), R33.1
/GPCLK0: J3.7, U1.33 (IO40)
/GROVE0: J3.32, J4.4 (IO1), R42.1, U1.38 (IO2)
/GROVE1: J3.33, J4.3 (IO2), R43.1, U1.15 (IO3)
/I2C0_SCL: J3.28, R15.1, U1.11 (IO18), U2.22 (SCL), U6.5 (SCL)
/I2C0_SDA: J3.27, R14.1, U1.10 (IO17), U2.23 (SDA), U6.6 (SDA)
/I2C1_SCL: J3.5, J5.4, J8.3, R6.1, U1.25 (IO48)
/I2C1_SDA: J3.3, J5.3, J8.4, R4.1, U1.24 (IO47)
/PCM_CLK: J3.12, U1.4 (IO4)
/PCM_DIN: J3.38, U1.6 (IO6)
/PCM_DOUT: J3.40, U1.7 (IO7)
/PCM_FS: J3.35, U1.5 (IO5)
/PREVGH: C24.1, D6.1 (K), J7.21 (VGH)
/PREVGL: C43.2, D2.2 (A), J7.23 (VGL)
/PRE_VBUS: FB2.2, J1.A4 (VBUS), J1.A9 (VBUS), J1.B4 (VBUS), J1.B9 (VBUS)
/REGN: C14.1, D1.2 (A), R7.2, U6.22 (REGN)
/RESE: J7.3 (RESE), Q1.2 (S), R35.1
/RXD: J3.10, U1.36 (RXD0)
/SAO_GPIO1: J3.18, J5.5, J8.6, U1.8 (IO15)
/SAO_GPIO2: J3.22, J5.6, J8.5, U1.9 (IO16)
/SPI_BUSY_EPD: J3.36, J7.9 (BUSY), U1.35 (IO42)
/SPI_CS0: R39.2, SW16.1 (A), U1.17 (IO9)
/SPI_CS1: R40.2, SW15.1 (A), U1.22 (IO14)
/SPI_CS_EPD: J7.12 (CS), R38.2, SW16.3 (C), U1.34 (IO41)
/SPI_CS_TR01: R37.2, SW15.3 (C), U1.18 (IO10), U3.8 (~CSN)
/SPI_DC_EPD: J3.29, J7.11 (D/C), U1.26 (IO45)
/SPI_MISO: J3.21, R3.2, U1.19 (IO11), U3.6 (SDO)
/SPI_MOSI: J3.19, J7.14 (SDA), U1.21 (IO13), U3.5 (SDI)
/SPI_RST_EPD: J3.31, J7.10 (RES), U1.16 (IO46)
/SPI_SCLK: J3.23, J7.13 (SCL), U1.20 (IO12), U3.7 (SCK)
/TR01_IRQ: J3.37, R36.1, U1.31 (IO38), U3.4 (GPO/IRQ)
/TXD: J3.8, U1.37 (TXD0)
/USB_D+: D8.1 (A1), J1.A6 (D+), J1.B6 (D+), U1.14 (USB_D+), U6.2 (D+)
/USB_D-: D7.1 (A1), J1.A7 (D-), J1.B7 (D-), U1.13 (USB_D-), U6.3 (D-)
GND: C1.2, C2.2, C3.2, C4.2, C5.2, C6.2, C7.2, C8.2, C9.2, C10.2, C11.2, C12.2, C13.2, C14.2, C15.1, C16.1, C17.2, C18.1, C19.1, C20.1, C21.1, C22.1, C24.2, C25.1, C26.1, C27.1, C28.1, C29.1, C30.1, C31.1, C32.1, C33.2, C34.2, C36.2, C37.2, C38.1, C39.2, C40.1, C41.1, C42.1, C43.1, C44.2, C45.2, C46.1, C47.1, C48.1, D3.1 (A1), D5.1 (K), D7.2 (A2), D8.2 (A2), J1.A1 (GND), J1.A12 (GND), J1.B1 (GND), J1.B12 (GND), J1.S1 (SHIELD), J2.2, J2.MP (MountPin), J3.6, J3.9, J3.14, J3.20, J3.25, J3.30, J3.34, J3.39, J4.1 (GND), J4.MP, J5.2, J7.8 (BS), J7.17 (VSS), J8.1, Q2.2 (S), R1.1, R2.1, R11.2, R19.2, R22.2, R33.2, R34.2, R35.2, R36.2, R45.2, R46.1, R47.1, SW0.2, SW1.2, SW2.2, SW3.2, SW4.2, SW5.2, SW6.2, SW7.2, SW8.2, SW9.2, SW10.2, SW11.2, SW12.1, SW13.1, SW14.1, TH2.2, TP7.1, U1.1 (GND), U1.40 (GND), U1.41 (GND), U2.2 (A1), U2.3 (A2), U2.12 (GND), U2.21 (A0), U3.2 (GND), U3.3 (PULLDN), U3.9 (PULLDN), U3.10 (PULLDN), U3.12 (GND), U3.23 (GND), U3.30 (PULLDN), U3.31 (PULLDN), U3.33 (TP), U5.2 (GND), U6.17 (PGND), U6.18 (PGND), U6.25 (PGND), U8.2 (GND)
unnamed: C35.1, L1.1, U6.19 (SW), U6.20 (SW)
unnamed: D1.1 (K), R13.2
unnamed: C23.1, D2.1 (K), D5.2 (A)
unnamed: D4.1 (K), R17.2
unnamed: C23.2, D6.2 (A), L4.2, Q1.3 (D)
unnamed: J1.A5 (CC1), R2.2
unnamed: J1.B5 (CC2), R1.2
unnamed: C1.1, J2.1, TP6.1, U6.13 (BAT), U6.14 (BAT)
unnamed: J3.24, SW16.2 (B)
unnamed: J3.26, SW15.2 (B)
unnamed: C46.2, J4.2 (VCC), JP1.2 (C)
unnamed: J6.1, J6.2, R32.1
unnamed: C44.1, J7.24 (VCOM)
unnamed: C40.2, J7.18 (VDD)
unnamed: C41.2, J7.20 (VSH1)
unnamed: C38.2, J7.5 (VSH2)
unnamed: C42.2, J7.22 (VSL)
unnamed: Q2.3 (D), R32.2
unnamed: C15.2, R5.1, SW13.2, U1.3 (EN)
unnamed: C16.2, R8.1, R17.1, SW14.2, U1.27 (IO0)
unnamed: L3.2, U5.1 (SW)
unnamed: C49.2, R44.2, R45.1, U5.4 (V_{FB})
unnamed: C35.2, U6.21 (BTST)
unnamed: R11.1, U6.10 (ILIM)
unnamed: R47.2, U6.8 (OTG)
unnamed: C11.1, U6.23 (PMID)
unnamed: R13.1, U6.4 (STAT)
unnamed: R7.1, R19.1, TH2.1, U6.11 (TS)
unnamed: R46.2, U6.9 (~CE)
unnamed: C18.2, SW12.2, U6.12 (~QON)
unnamed: C50.2, R21.2, R22.1, U8.5 (FB)
unnamed: L2.1, U8.3 (SW)
VBUS: C33.1, D3.2 (A2), FB2.1, TP1.1, U6.1 (VBUS)
VSYS: C6.1, C13.1, C36.1, C37.1, L1.2, L3.1, TP2.1, U5.3 (EN), U5.6 (V_{IN}), U6.15 (SYS), U6.16 (SYS), U8.1 (EN), U8.4 (VIN)

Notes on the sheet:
MCU ESP32-S3
Connected to the Octal SPI PSRAM. Not available for other uses.
Mounting Holes
3.3V Buck Converter
pull-downs to allow hacking
scratch for power glitching
INPUT
Charging temp [0,45] °C
USB-C Connector
E-Paper Display
Keypad
IO Expander
Grove Connector
Secure Element
Raspberry Pi Header
Divider dissipates 66 µW / 20uA
max input 220Ω = 1.7A
5V Boost Converter
SAO port
Charging IC
E-Paper Frontlight
Quiescent currents: 1.950mA idle mode 0.945mA sleep mode
Quiescent currents: 95mA WiFi listening 22mA single-core 40 MHz 240μA light-sleep mode 8μA deep sleep mode
1mA 90% efficiency 1A 92% efficiency 2A 87% efficiency max current: 2.5A feedback: 0.5V 20μA quiescent
1mA 80% efficiency 1A 95% efficiency 2A 91% efficiency feedback: 0.6V 35μA quiescent
Default charge current is 2A. LiPo rated at 1.2A max. Lower in firmware!
11μA quiescent
Quiescent currents: 12μA BATFET disabled 32μA BATFET enabled
Quiescent currents: 20μA sleep mode 1μA deep sleep mode

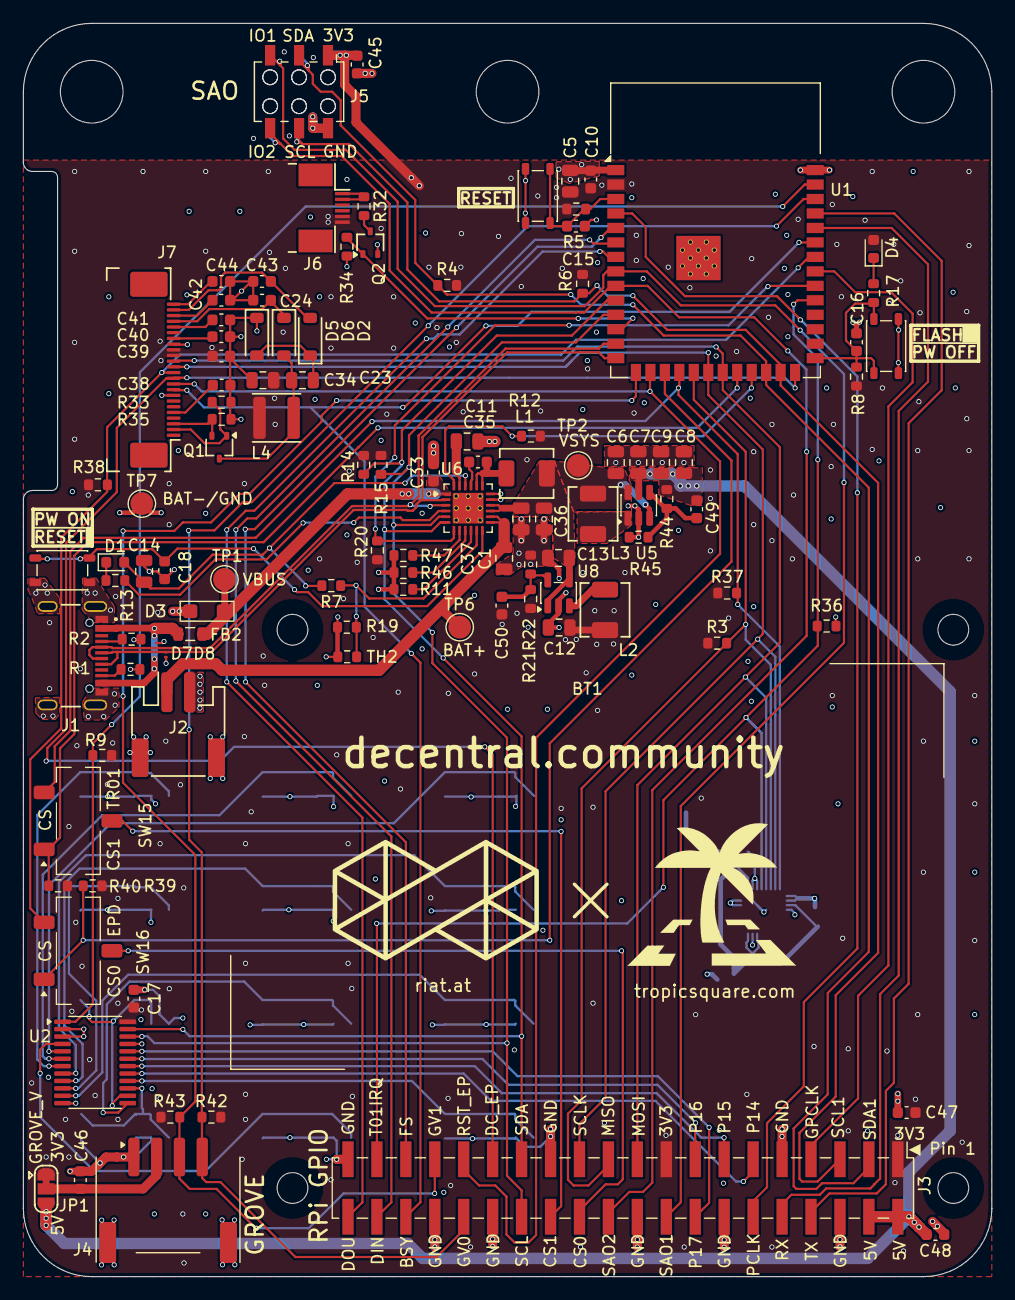
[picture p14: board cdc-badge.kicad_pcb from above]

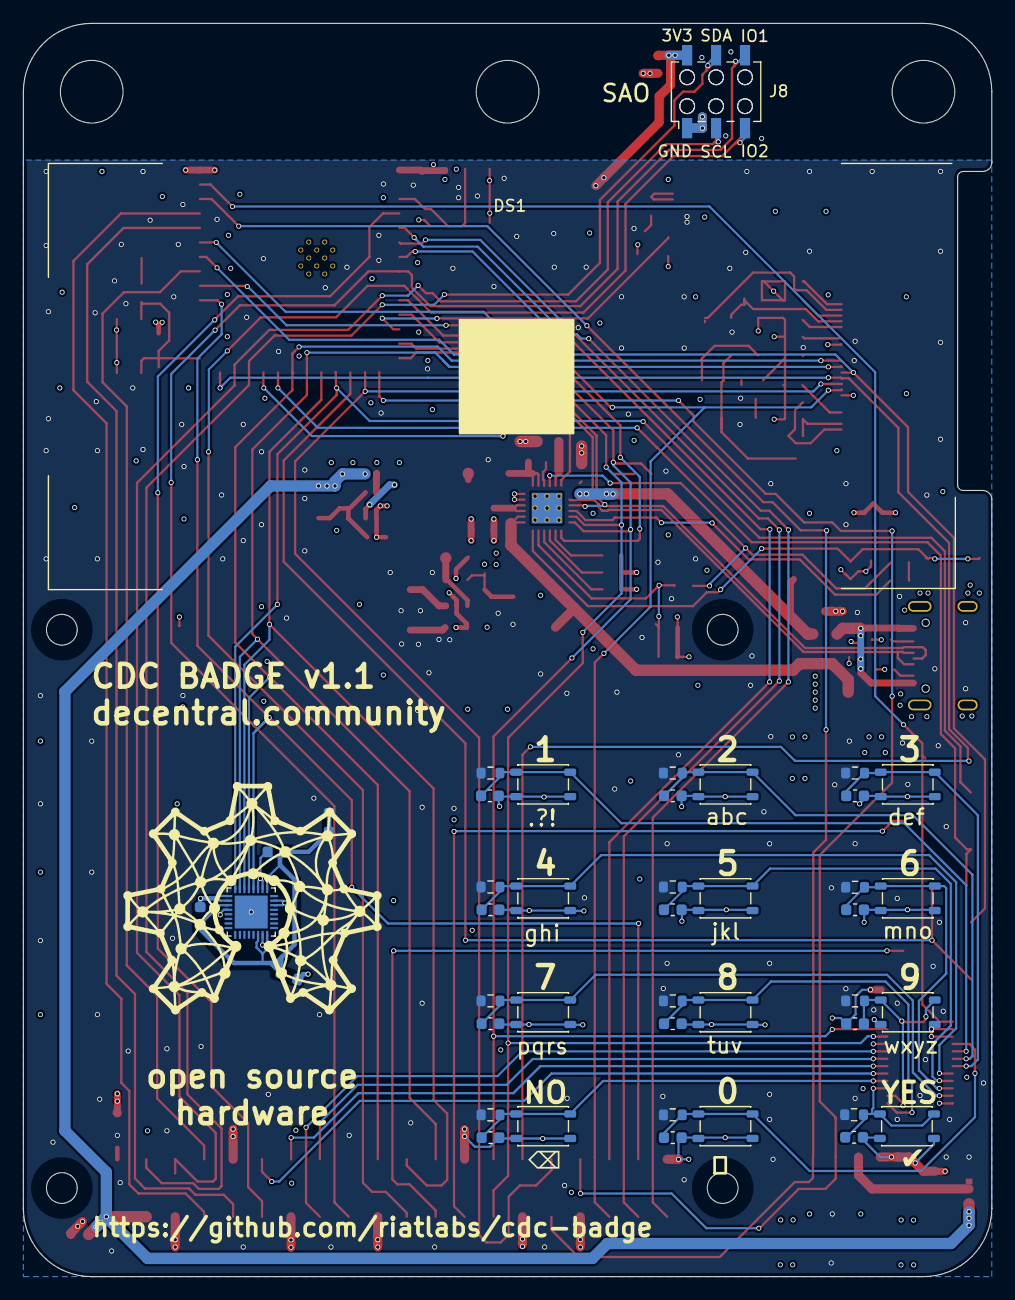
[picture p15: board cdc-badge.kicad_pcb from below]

Board: 4 copper layers, 85.0 x 110.0 mm, 158 parts (43 on the bottom side), 91 nets.

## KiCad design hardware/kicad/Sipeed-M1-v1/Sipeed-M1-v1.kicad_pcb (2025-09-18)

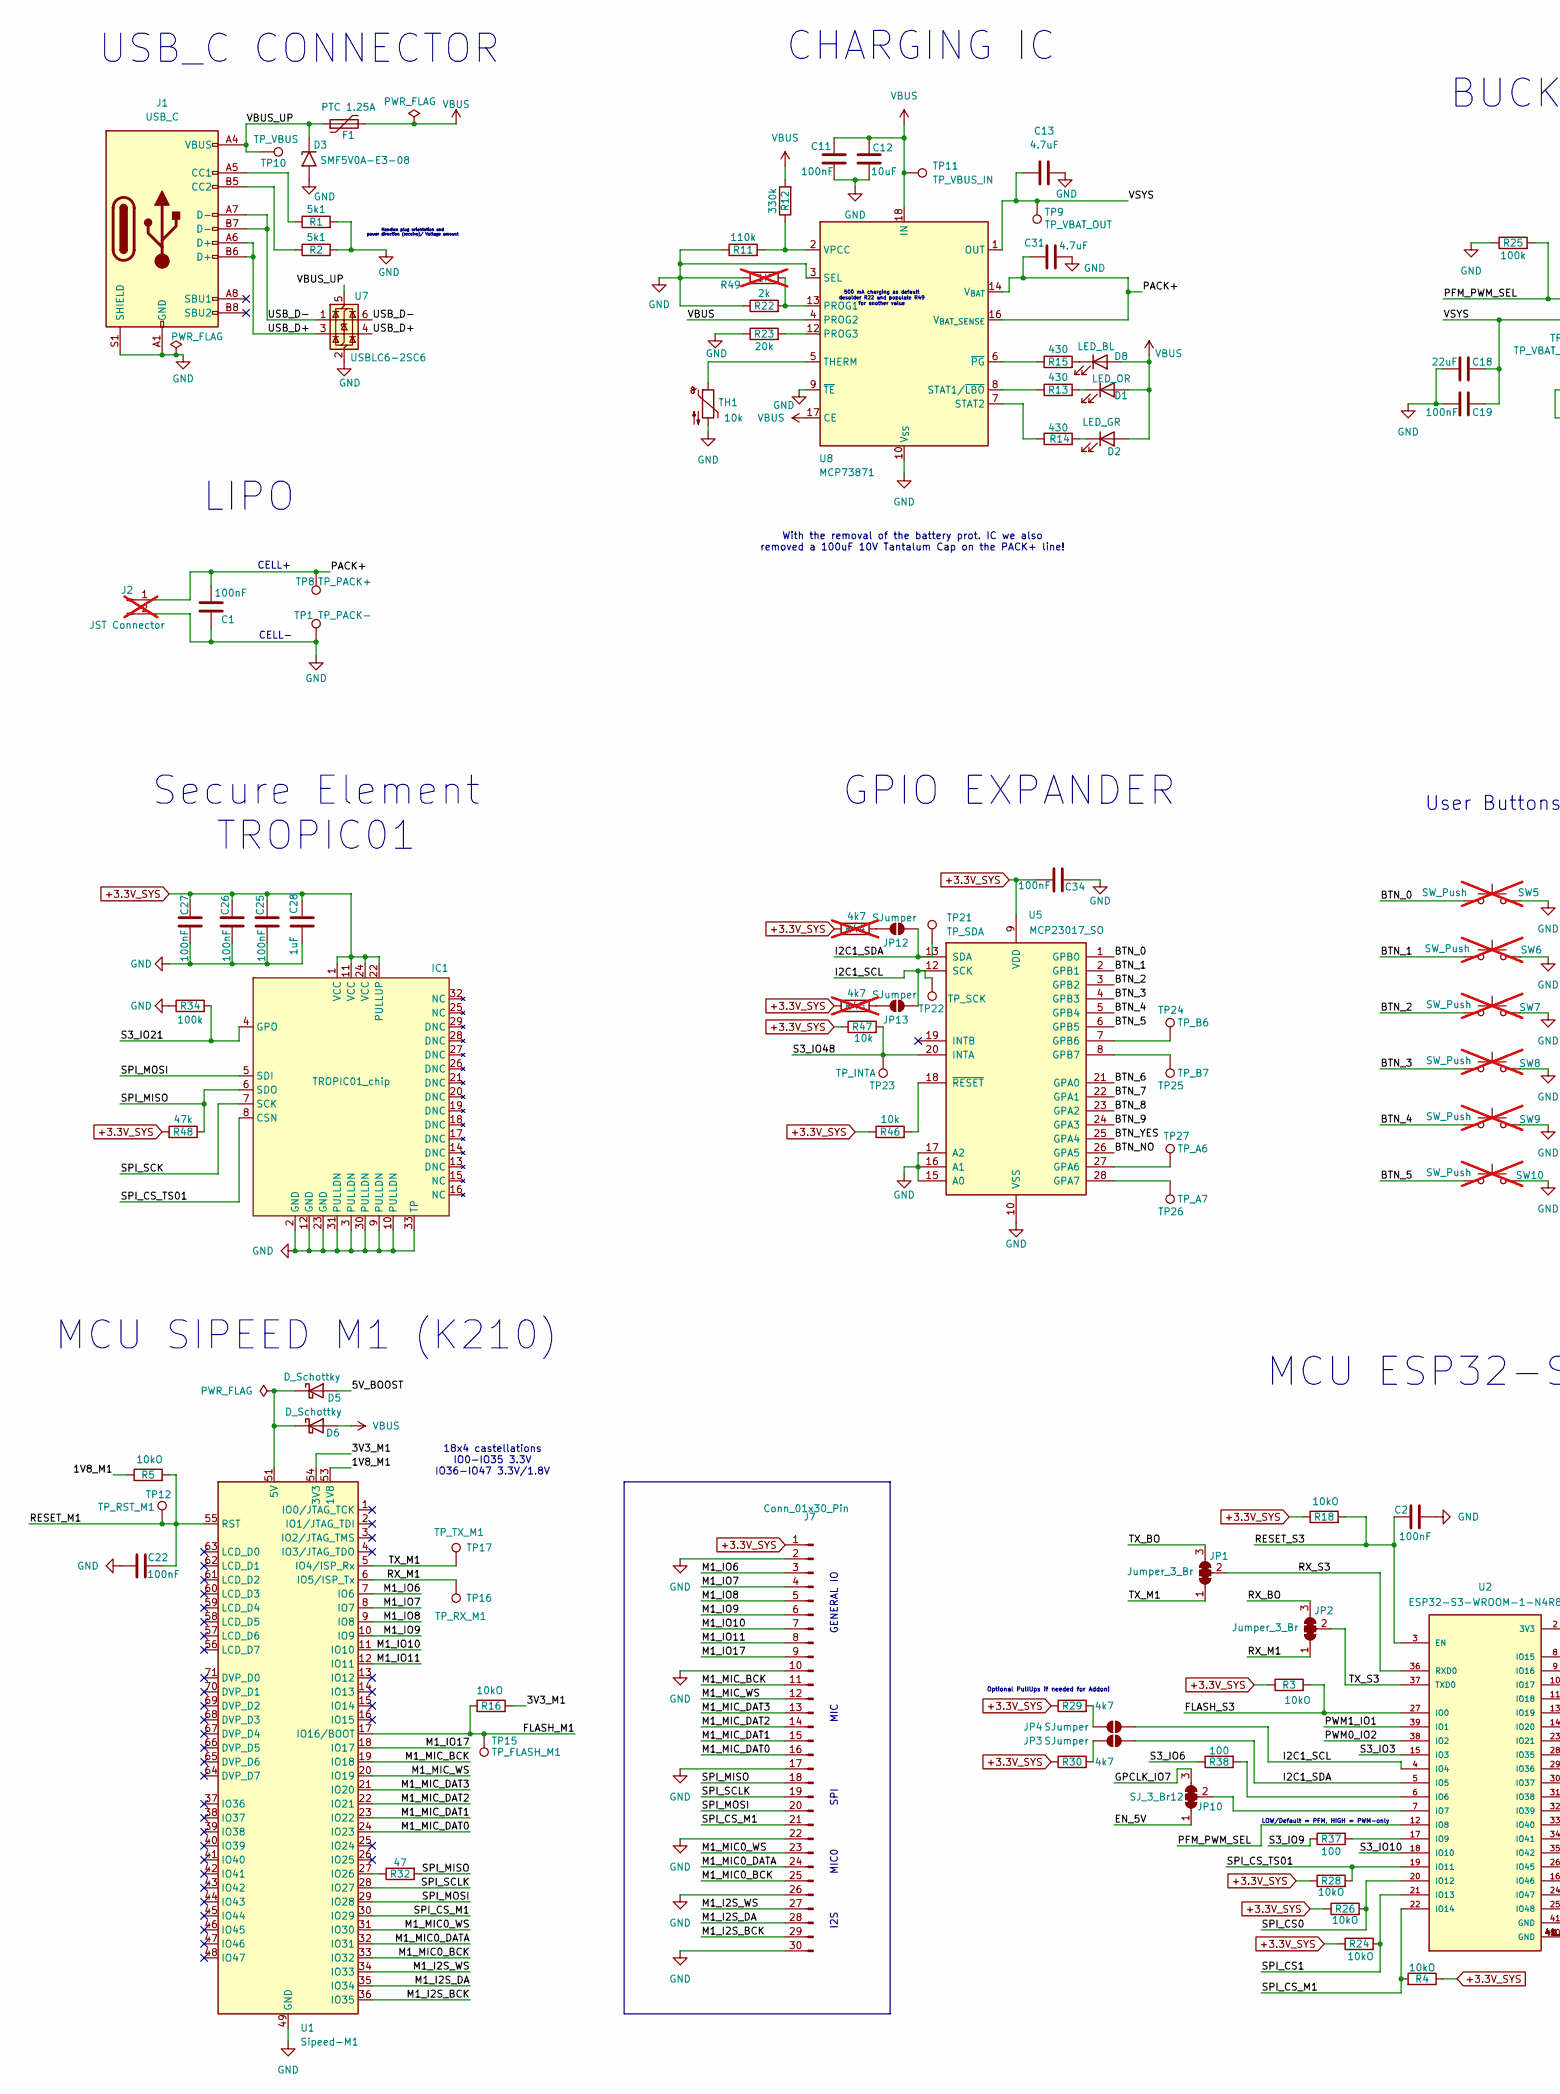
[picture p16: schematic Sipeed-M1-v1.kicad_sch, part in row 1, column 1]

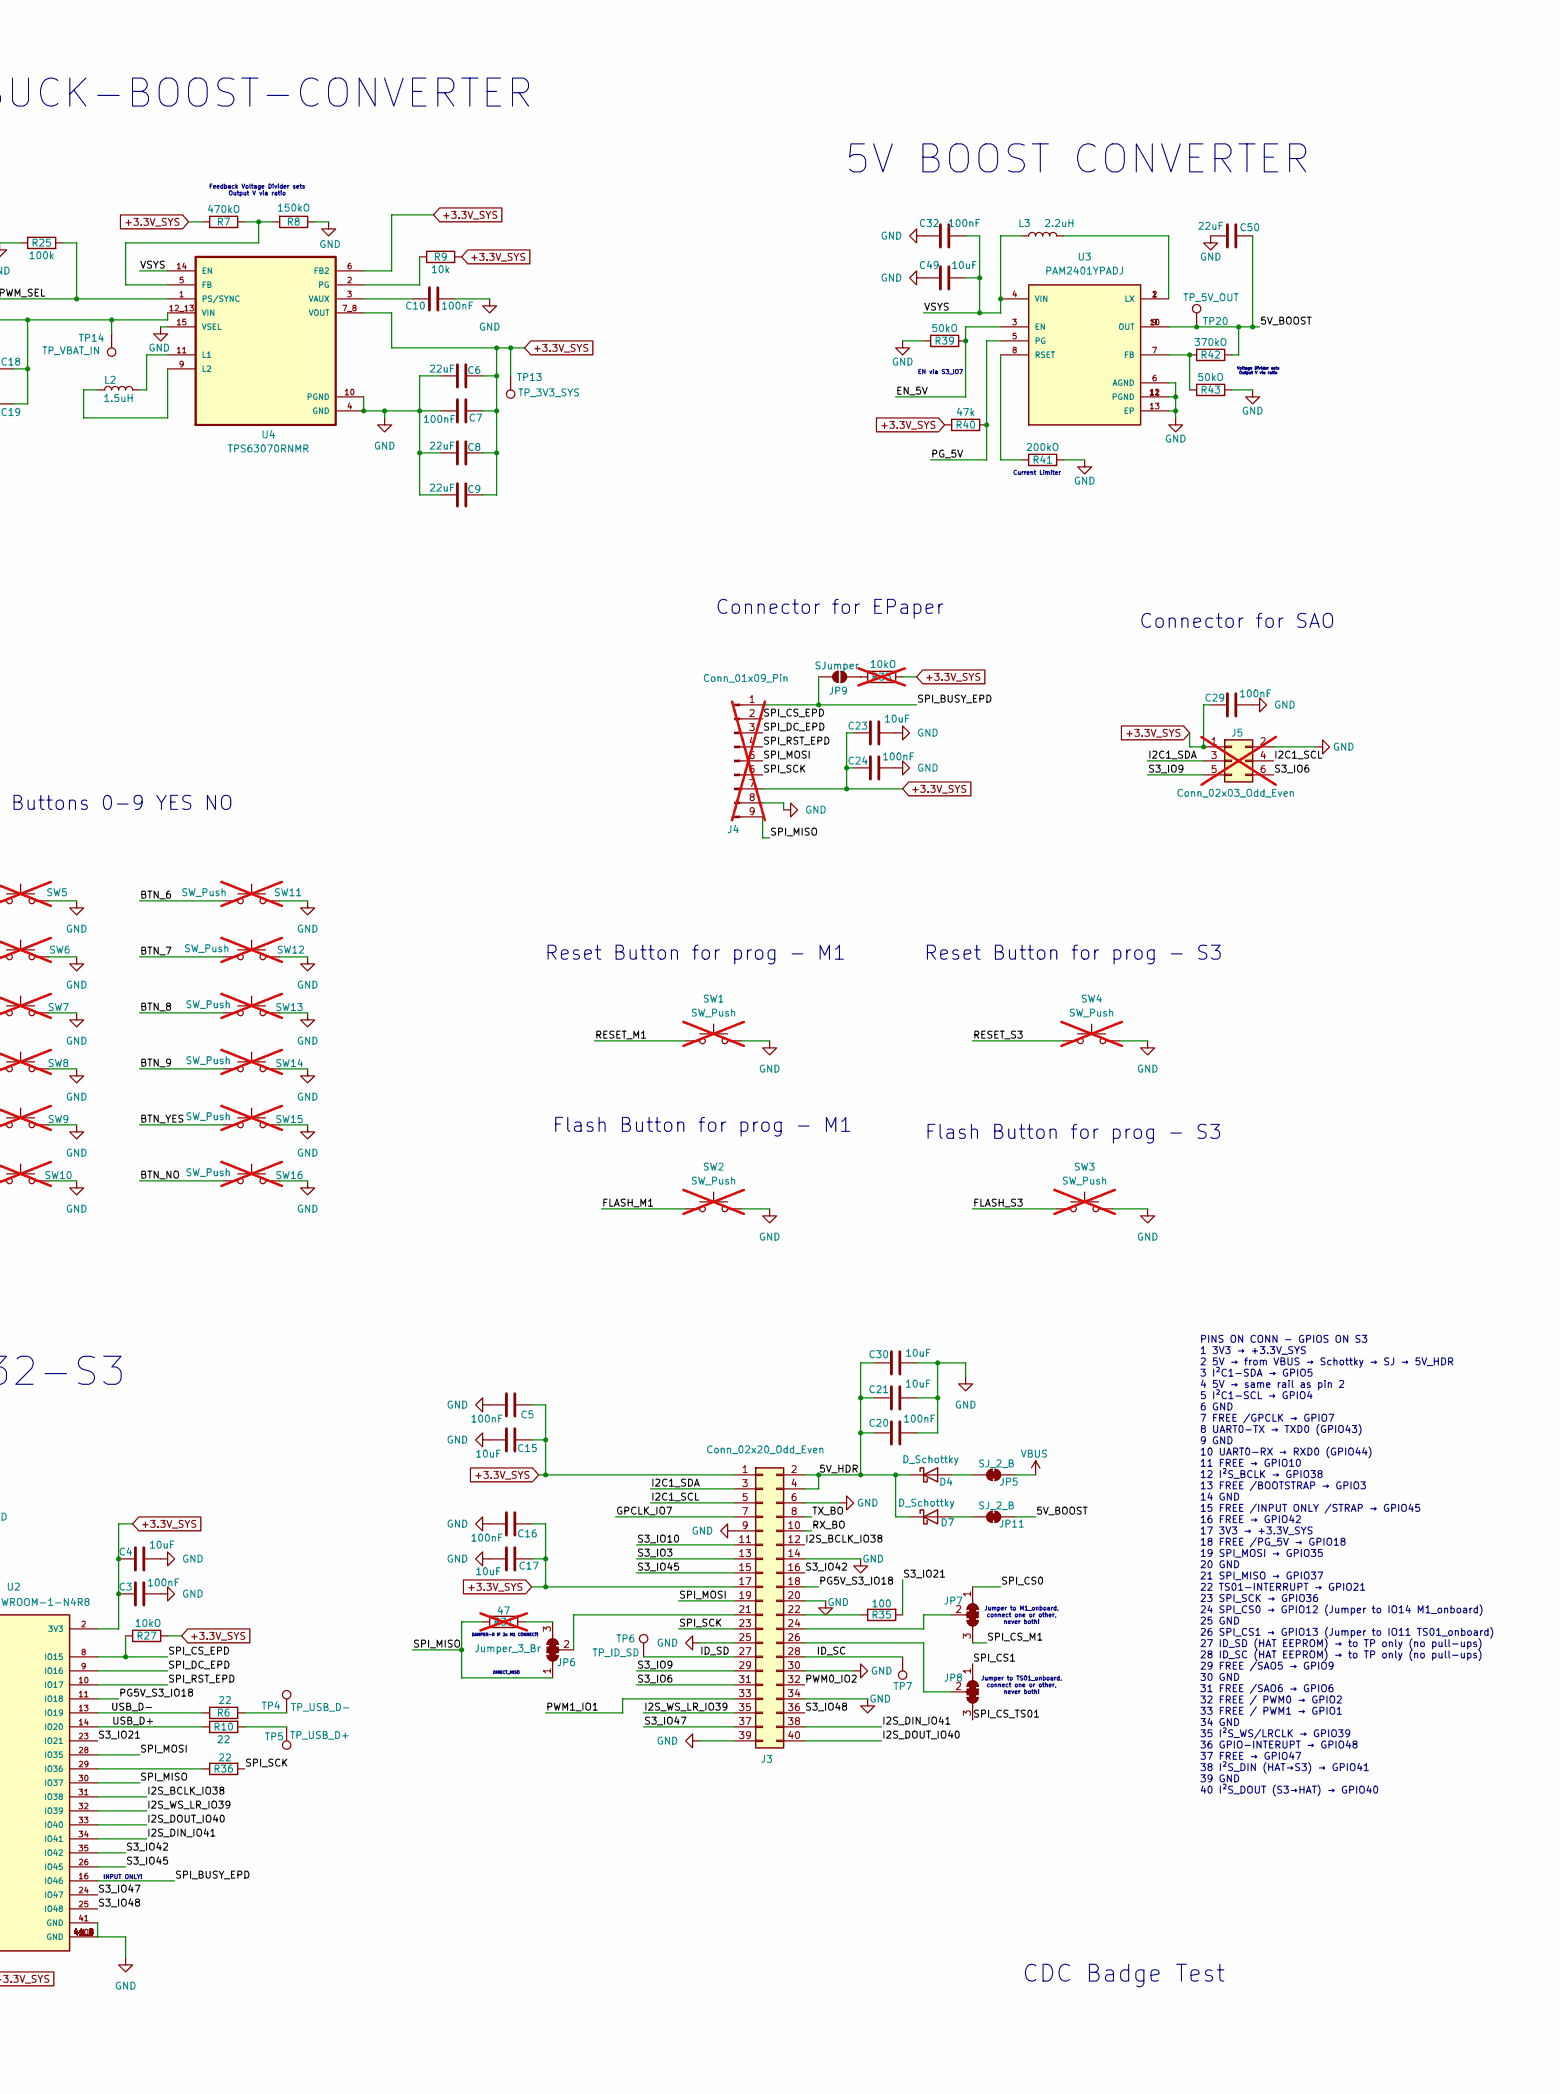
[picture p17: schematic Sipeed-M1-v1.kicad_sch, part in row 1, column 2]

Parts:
C1, C2, C3, C5, C7, C10, C11, C16, C19, C20, C22, C24, C25, C26, C27, C29, C34: 100nF; C_0603_1608Metric
C4, C12, C15, C17, C21, C23, C30: 10uF; C_1206_3216Metric
C6, C8, C9, C18: 22uF; C_1206_3216Metric
C13, C31: 4.7uF; C_1206_3216Metric
C28: 1uF; C_0805_2012Metric
C32: 100nF; CP_EIA-3528-12_Kemet-T
C49: 10uF; CP_EIA-3528-12_Kemet-T
C50: 22uF; CP_EIA-3528-12_Kemet-T
D1: LED_OR; LED_0603_1608Metric
D2: LED_GR; LED_0603_1608Metric
D3: SMF5V0A-E3-08; D_SMF; JLCPCB PN C1972946
D4, D5, D6, D7: D_Schottky; D_SOD-123F
D8: LED_BL; LED_0603_1608Metric
F1: PTC 1.25A; Fuse_1812_4532Metric
IC1: TROPIC01_chip; TROPIC_QFN-32-1EP_4x4mm_P0.4mm_EP2.65x2.65mm
J1: USB_C; SHOUHAN_TYPE-C_16PIN_2MD__073_; JLCPCB PN C2765186
J2: JST Connector; JST_PH_S2B-PH-SM4-TB_1x02-1MP_P2.00mm_Horizontal; not fitted
J3: Conn_02x20_Odd_Even; PinHeader_2x20_P2.54mm_Vertical
J4: Conn_01x09_Pin; PinHeader_1x09_P2.54mm_Vertical; not fitted
J5: Conn_02x03_Odd_Even; PinSocket_2x03_P2.54mm_Vertical; not fitted
J7: Conn_01x30_Pin; PinHeader_1x30_P2.54mm_Vertical
JP1, JP2, JP6: Jumper_3_Br; SolderJumper-3_P1.3mm_Bridged12_RoundedPad1.0x1.5mm_NumberL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
JP3, JP4: SJumper; SolderJumper-2_P1.3mm_Bridged_RoundedPad1.0x1.5mm
JP5, JP11: SJ_2_B; SolderJumper-2_P1.3mm_Bridged_RoundedPad1.0x1.5mm
JP7, JP8: Jump_3_Br12; SolderJumper-3_P1.3mm_Bridged12_RoundedPad1.0x1.5mm_NumberL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
JP9, JP12, JP13: SJumper; SolderJumper-2_P1.3mm_Open_RoundedPad1.0x1.5mm
JP10: SJ_3_Br12; SolderJumper-3_P1.3mm_Bridged12_RoundedPad1.0x1.5mm_NumberL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
L2: 1.5uH; L_6.3x6.3_H3
L3: 2.2uH; L_6.3x6.3_H3
R1, R2: 5k1; R_0402_1005Metric
R3, R4, R5, R16, R18, R24, R26, R27, R28: 10kO; R_0603_1608Metric
R6, R10, R36: 22; R_0603_1608Metric
R7: 470kO; R_0805_2012Metric
R8: 150kO; R_0805_2012Metric
R9, R46, R47: 10k; R_0603_1608Metric
R11: 110k; R_0805_2012Metric
R12: 330k; R_0805_2012Metric
R13, R14, R15: 430; R_0603_1608Metric
R22: 2k; R_0603_1608Metric
R23: 20k; R_0603_1608Metric
R25: 100k; R_0805_2012Metric
R29, R30: 4k7; R_0603_1608Metric
R31: 47; R_Axial_DIN0207_L6.3mm_D2.5mm_P7.62mm_Horizontal; not fitted
R32: 47; R_0603_1608Metric
R33: 10kO; R_Axial_DIN0207_L6.3mm_D2.5mm_P7.62mm_Horizontal; not fitted
R34: 100k; R_0603_1608Metric
R35, R37, R38: 100; R_0603_1608Metric
R39, R43: 50kO; R_0603_1608Metric
R40, R48: 47k; R_0603_1608Metric
R41: 200kO; R_0805_2012Metric
R42: 370kO; R_0805_2012Metric
R44, R45: 4k7; R_Axial_DIN0207_L6.3mm_D2.5mm_P7.62mm_Horizontal; not fitted
R49: 1K; R_Axial_DIN0207_L6.3mm_D2.5mm_P7.62mm_Horizontal; not fitted
SW1, SW2, SW3, SW4, SW5, SW6, SW7, SW8, SW9, SW10, SW11, SW12, SW13, SW14, SW15, SW16: SW_Push; SW_PUSH_6mm_H5mm; not fitted
TH1: 10k; Fuse_1812_4532Metric
TP1: TP_PACK-; TestPoint_Pad_D2.0mm
TP4: TP_USB_D-; TestPoint_Pad_D2.0mm
TP5: TP_USB_D+; TestPoint_Pad_D2.0mm
TP6: TP_ID_SD; TestPoint_Pad_D2.0mm
TP7: TP_ID_SC; TestPoint_Pad_D2.0mm
TP8: TP_PACK+; TestPoint_Pad_D2.0mm
TP9: TP_VBAT_OUT; TestPoint_Pad_D2.0mm
TP10: TP_VBUS; TestPoint_Pad_D2.0mm
TP11: TP_VBUS_IN; TestPoint_Pad_D2.0mm
TP12: TP_RST_M1; TestPoint_Pad_D2.0mm
TP13: TP_3V3_SYS; TestPoint_Pad_D2.0mm
TP14: TP_VBAT_IN; TestPoint_Pad_D2.0mm
TP15: TP_FLASH_M1; TestPoint_Pad_D2.0mm
TP16: TP_RX_M1; TestPoint_Pad_D2.0mm
TP17: TP_TX_M1; TestPoint_Pad_D2.0mm
TP20: TP_5V_OUT; TestPoint_Pad_D2.0mm
TP21: TP_SDA; TestPoint_Pad_D2.0mm
TP22: TP_SCK; TestPoint_Pad_D2.0mm
TP23: TP_INTA; TestPoint_Pad_D2.0mm
TP24: TP_B6; TestPoint_Pad_D2.0mm
TP25: TP_B7; TestPoint_Pad_D2.0mm
TP26: TP_A7; TestPoint_Pad_D2.0mm
TP27: TP_A6; TestPoint_Pad_D2.0mm
U1: Sipeed-M1
U2: ESP32-S3-WROOM-1-N4R8; ESP32-S3-WROOM-1; PARTREV v1.1
U3: PAM2401YPADJ; PAM2401_SON45P300X300X63-13N; PARTREV 1-2
U4: TPS63070RNMR
U5: MCP23017_SO; SOIC-28W_7.5x17.9mm_P1.27mm
U7: USBLC6-2SC6; SOT-23-6; JLCPCB PN C7519
U8: MCP73871; QFN-20-1EP_4x4mm_P0.5mm_EP2.5x2.5mm

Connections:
+3.3V_SYS: C3.1, C4.1, C5.1, C6.2, C7.2, C8.2, C9.2, C15.1, C16.1, C17.1, C23.1, C24.1, C25.1, C26.1, C27.1, C28.1, C29.1, C34.2, IC1.1 (VCC), IC1.11 (VCC), IC1.22 (PULLUP), IC1.24 (VCC), J3.1, J3.17, J4.7, J5.1, J7.1, R3.1, R4.1, R7.1, R9.2, R18.1, R24.1, R26.1, R27.1, R28.1, R29.1, R30.1, R33.1, R40.2, R44.1, R45.1, R46.1, R47.1, R48.2, TP13.1, U2.2 (3V3), U4.6 (FB2), U4.7_8 (VOUT), U5.9 (VDD)
/1V8_M1: R5.1, U1.53 (1V8)
/3V3_M1: R16.1, U1.54 (3V3)
/5V_BOOST: C50.1, D5.2 (A), JP11.2 (B), R42.2, TP20.1, U3.9 (OUT), U3.10 (OUT)
/5V_HDR: C20.1, C21.1, C30.1, D4.1 (K), D7.1 (K), J3.2, J3.4
/BTN_0: SW5.1, U5.1 (GPB0)
/BTN_1: SW6.1, U5.2 (GPB1)
/BTN_2: SW7.1, U5.3 (GPB2)
/BTN_3: SW8.1, U5.4 (GPB3)
/BTN_4: SW9.1, U5.5 (GPB4)
/BTN_5: SW10.1, U5.6 (GPB5)
/BTN_6: SW11.1, U5.21 (GPA0)
/BTN_7: SW12.1, U5.22 (GPA1)
/BTN_8: SW13.1, U5.23 (GPA2)
/BTN_9: SW14.1, U5.24 (GPA3)
/BTN_NO: SW16.1, U5.26 (GPA5)
/BTN_YES: SW15.1, U5.25 (GPA4)
/EN_5V: JP10.1 (A), R39.1, U3.3 (EN)
/FLASH_M1: R16.2, SW2.1, TP15.1, U1.17 (IO16/BOOT)
/FLASH_S3: R3.2, SW3.1, U2.27 (IO0)
/GPCLK_IO7: J3.7, JP10.3 (B)
/I2C1_SCL: J3.5, J5.4, JP4.2 (B), JP13.2 (B), TP22.1, U2.4 (IO4), U5.12 (SCK)
/I2C1_SDA: J3.3, J5.3, JP3.2 (B), JP12.2 (B), TP21.1, U2.5 (IO5), U5.13 (SDA)
/I2S_BCLK_IO38: J3.12, U2.31 (IO38)
/I2S_DIN_IO41: J3.38, U2.34 (IO41)
/I2S_DOUT_IO40: J3.40, U2.33 (IO40)
/I2S_WS_LR_IO39: J3.35, U2.32 (IO39)
/ID_SC: J3.28, TP7.1
/ID_SD: J3.27, TP6.1
/M1_I2S_BCK: J7.29, U1.36 (IO35)
/M1_I2S_DA: J7.28, U1.35 (IO34)
/M1_I2S_WS: J7.27, U1.34 (IO33)
/M1_IO6: J7.3, U1.7 (IO6)
/M1_IO7: J7.4, U1.8 (IO7)
/M1_IO8: J7.5, U1.9 (IO8)
/M1_IO9: J7.6, U1.10 (IO9)
/M1_IO10: J7.7, U1.11 (IO10)
/M1_IO11: J7.8, U1.12 (IO11)
/M1_IO17: J7.9, U1.18 (IO17)
/M1_MIC0_BCK: J7.25, U1.33 (IO32)
/M1_MIC0_DATA: J7.24, U1.32 (IO31)
/M1_MIC0_WS: J7.23, U1.31 (IO30)
/M1_MIC_BCK: J7.11, U1.19 (IO18)
/M1_MIC_DAT0: J7.16, U1.24 (IO23)
/M1_MIC_DAT1: J7.15, U1.23 (IO22)
/M1_MIC_DAT2: J7.14, U1.22 (IO21)
/M1_MIC_DAT3: J7.13, U1.21 (IO20)
/M1_MIC_WS: J7.12, U1.20 (IO19)
/PACK+: C1.2, C31.1, J2.1, TP8.1, U8.14 (V_{BAT}), U8.15 (V_{BAT}), U8.16 (V_{BAT_SENSE})
/PFM_PWM_SEL: R25.2, U2.12 (IO8), U4.1 (PS/SYNC)
/PG5V_S3_IO18: J3.18, U2.11 (IO18)
/PG_5V: R40.1, U3.5 (PG)
/PWM0_IO2: J3.32, U2.38 (IO2)
/PWM1_IO1: J3.33, U2.39 (IO1)
/RESET_M1: C22.1, R5.2, SW1.1, TP12.1, U1.55 (RST)
/RESET_S3: C2.1, R18.2, SW4.1, U2.3 (EN)
/RX_BO: J3.10, JP2.3 (B)
/RX_M1: JP2.1 (A), TP16.1, U1.6 (IO5/ISP_Tx)
/RX_S3: JP1.2 (C), U2.36 (RXD0)
/S3_IO3: J3.13, U2.15 (IO3)
/S3_IO6: J3.31, J5.6, R38.1
/S3_IO9: J3.29, J5.5, R37.1
/S3_IO10: J3.11, U2.18 (IO10)
/S3_IO21: IC1.4 (GPO), R34.2, R35.2, U2.23 (IO21)
/S3_IO42: J3.16, U2.35 (IO42)
/S3_IO45: J3.15, U2.26 (IO45)
/S3_IO47: J3.37, U2.24 (IO47)
/S3_IO48: J3.36, R47.2, TP23.1, U2.25 (IO48), U5.20 (INTA)
/SPI_BUSY_EPD: J4.1, JP9.1 (A), U2.16 (IO46)
/SPI_CS0: JP7.1 (A), R26.2, U2.20 (IO12)
/SPI_CS1: JP8.1 (A), R24.2, U2.21 (IO13)
/SPI_CS_EPD: J4.2, R27.2, U2.8 (IO15)
/SPI_CS_M1: J7.21, JP7.3 (B), R4.2, U1.30 (IO29), U2.22 (IO14)
/SPI_CS_TS01: IC1.8 (CSN), JP8.3 (B), R28.2, U2.19 (IO11)
/SPI_DC_EPD: J4.3, U2.9 (IO16)
/SPI_MISO: IC1.6 (SDO), J4.9, J7.18, JP6.1 (A), R31.1, R32.2, R48.1, U2.30 (IO37)
/SPI_MOSI: IC1.5 (SDI), J3.19, J4.5, J7.20, U1.29 (IO28), U2.28 (IO35)
/SPI_RST_EPD: J4.4, U2.10 (IO17)
/SPI_SCK: IC1.7 (SCK), J3.23, J4.6, R36.2
/SPI_SCLK: J7.19, U1.28 (IO27)
/TX_BO: J3.8, JP1.3 (B)
/TX_M1: JP1.1 (A), TP17.1, U1.5 (IO4/ISP_Rx)
/TX_S3: JP2.2 (C), U2.37 (TXD0)
/USB_D+: J1.A6 (D+), J1.B6 (D+), R10.1, U2.14 (IO20), U7.3 (I/O2), U7.4 (I/O2)
/USB_D-: J1.A7 (D-), J1.B7 (D-), R6.2, U2.13 (IO19), U7.1 (I/O1), U7.6 (I/O1)
/VBUS_UP: D3.1 (A1), F1.1, J1.A4 (VBUS), J1.A9 (VBUS), J1.B4 (VBUS), J1.B9 (VBUS), TP10.1, U7.5 (VBUS)
/VSYS: C13.1, C18.2, C19.2, C32.1, C49.1, L3.1, TP9.1, TP14.1, U3.4 (VIN), U4.12_13 (VIN), U4.14 (EN), U8.1 (OUT), U8.20 (OUT)
GND: C1.1, C2.2, C3.2, C4.2, C5.2, C6.1, C7.1, C8.1, C9.1, C10.1, C11.2, C12.1, C13.2, C15.2, C16.2, C17.2, C18.1, C19.1, C20.2, C21.2, C22.2, C23.2, C24.2, C25.2, C26.2, C27.2, C28.2, C29.2, C30.2, C31.2, C32.2, C34.1, C49.2, C50.2, D3.2 (A2), IC1.2 (GND), IC1.3 (PULLDN), IC1.9 (PULLDN), IC1.10 (PULLDN), IC1.12 (GND), IC1.23 (GND), IC1.30 (PULLDN), IC1.31 (PULLDN), IC1.33 (TP), J1.A1 (GND), J1.A12 (GND), J1.B1 (GND), J1.B12 (GND), J1.S1 (SHIELD), J2.2, J3.6, J3.9, J3.14, J3.20, J3.25, J3.30, J3.34, J3.39, J4.8, J5.2, J7.2, J7.10, J7.17, J7.22, J7.26, J7.30, R1.2, R2.2, R8.1, R11.1, R22.1, R23.1, R25.1, R34.1, R39.2, R41.1, R43.2, R49.1, SW1.2, SW2.2, SW3.2, SW4.2, SW5.2, SW6.2, SW7.2, SW8.2, SW9.2, SW10.2, SW11.2, SW12.2, SW13.2, SW14.2, SW15.2, SW16.2, TH1.2, TP1.1, U1.49 (GND), U1.50 (GND), U1.72 (GND), U2.1 (GND), U2.40 (GND), U2.41 (GND), U2.41_1 (GND), U2.41_2 (GND), U2.41_3 (GND), U2.41_4 (GND), U2.41_5 (GND), U2.41_6 (GND), U2.41_7 (GND), U2.41_8 (GND), U2.41_9 (GND), U3.6 (AGND), U3.11 (PGND), U3.12 (PGND), U3.13 (EP), U4.4 (GND), U4.10 (PGND), U4.15 (VSEL), U5.10 (VSS), U5.15 (A0), U5.16 (A1), U5.17 (A2), U7.2 (GND), U8.3 (SEL), U8.9 (~TE), U8.10 (V_{SS}), U8.11 (V_{SS}), U8.21 (V_{SS})
unnamed: D1.1 (K), R13.2
unnamed: D2.1 (K), R14.2
unnamed: D4.2 (A), JP5.1 (A)
unnamed: D5.1 (K), D6.1 (K), U1.51 (5V), U1.52 (5V)
unnamed: D7.2 (A), JP11.1 (A)
unnamed: D8.1 (K), R15.2
unnamed: J1.A5 (CC1), R1.1
unnamed: J1.B5 (CC2), R2.1
unnamed: J3.21, JP6.2 (C)
unnamed: J3.22, R35.1
unnamed: J3.24, JP7.2 (C)
unnamed: J3.26, JP8.2 (C)
unnamed: JP3.1 (A), R30.2
unnamed: JP4.1 (A), R29.2
unnamed: JP6.3 (B), R31.2
unnamed: JP9.2 (B), R33.2
unnamed: JP10.2 (C), U2.7 (IO7)
unnamed: JP12.1 (A), R44.2
unnamed: JP13.1 (A), R45.2
unnamed: L3.2, U3.1 (LX), U3.2 (LX)
unnamed: R6.1, TP4.1
unnamed: R10.2, TP5.1
unnamed: R32.1, U1.27 (IO26)
unnamed: R38.2, U2.6 (IO6)
unnamed: R37.2, U2.17 (IO9)
unnamed: R36.1, U2.29 (IO36)
unnamed: R42.1, R43.1, U3.7 (FB)
unnamed: R41.2, U3.8 (RSET)
unnamed: R7.2, R8.2, U4.5 (FB)
unnamed: L2.2, U4.11 (L1)
unnamed: L2.1, U4.9 (L2)
unnamed: R9.1, U4.2 (PG)
unnamed: C10.2, U4.3 (VAUX)
unnamed: TP27.1, U5.27 (GPA6)
unnamed: TP26.1, U5.28 (GPA7)
unnamed: TP24.1, U5.7 (GPB6)
unnamed: TP25.1, U5.8 (GPB7)
unnamed: R46.2, U5.18 (~RESET)
unnamed: R22.2, R49.2, U8.13 (PROG1)
unnamed: R23.2, U8.12 (PROG3)
unnamed: R13.1, U8.8 (STAT1/~LBO)
unnamed: R14.1, U8.7 (STAT2)
unnamed: TH1.1, U8.5 (THERM)
unnamed: R11.2, R12.1, U8.2 (VPCC)
unnamed 134: R15.1, U8.6 (~PG); also elsewhere on the board
VBUS: C11.1, C12.2, D1.2 (A), D2.2 (A), D6.2 (A), D8.2 (A), F1.2, JP5.2 (B), R12.2, TP11.1, U8.4 (PROG2), U8.17 (CE), U8.18 (IN), U8.19 (IN); also elsewhere on the board

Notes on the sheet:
MCU ESP32-S3
User Buttons 0-9 YES NO
18x4 castellations IO0-IO35 3.3V IO36-IO47 3.3V/1.8V
BUCK-BOOST-CONVERTER
GENERAL IO
LIPO
MIC0
CELL-
Handles plug orientation and power direction (receive)/ Voltage amount
EN via S3_IO7
USB_C CONNECTOR
Connector for EPaper
Jumper to M1_onboard, connect one or other, never both!
Reset Button for prog - S3
CDC Badge Test
LOW/Default = PFM, HIGH = PWM-only
MIC
Reset Button for prog - M1
GPIO EXPANDER
Jumper to TS01_onboard, connect one or other, never both!
I2S
500 mA charging as default desolder R22 and populate R49 for another value
MCU SIPEED M1 (K210)
Flash Button for prog - S3
INPUT ONLY!
SPI
Optional PullUps if needed for Addon!
Secure Element TROPIC01
Voltage Divider sets Output V via ratio
DAMPER-R IF 2x M1 CONNECT!
Current Limiter
5V BOOST CONVERTER
PINS ON CONN - GPIOS ON S3 1 3V3 → +3.3V_SYS 2 5V → from VBUS → Schottky → SJ → 5V_HDR 3 I²C1-SDA → GPIO5 4 5V → same rail as pin 2 5 I²C1-SCL → GPIO4 6 GND 7 FREE /GPCLK → GPIO7 8 UART0-TX → TXD0 (GPIO43) 9 GND 10 UART0-RX → RXD0 (GPIO44) 11 FREE → GPIO10 12 I²S_BCLK → GPIO38 13 FREE /BOOTSTRAP → 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
CELL+
Connector for SAO
With the removal of the battery prot. IC we also removed a 100uF 10V Tantalum Cap on the PACK+ line!
Flash Button for prog - M1
DIRECT_MISO
CHARGING IC
Feedback Voltage Divider sets Output V via ratio

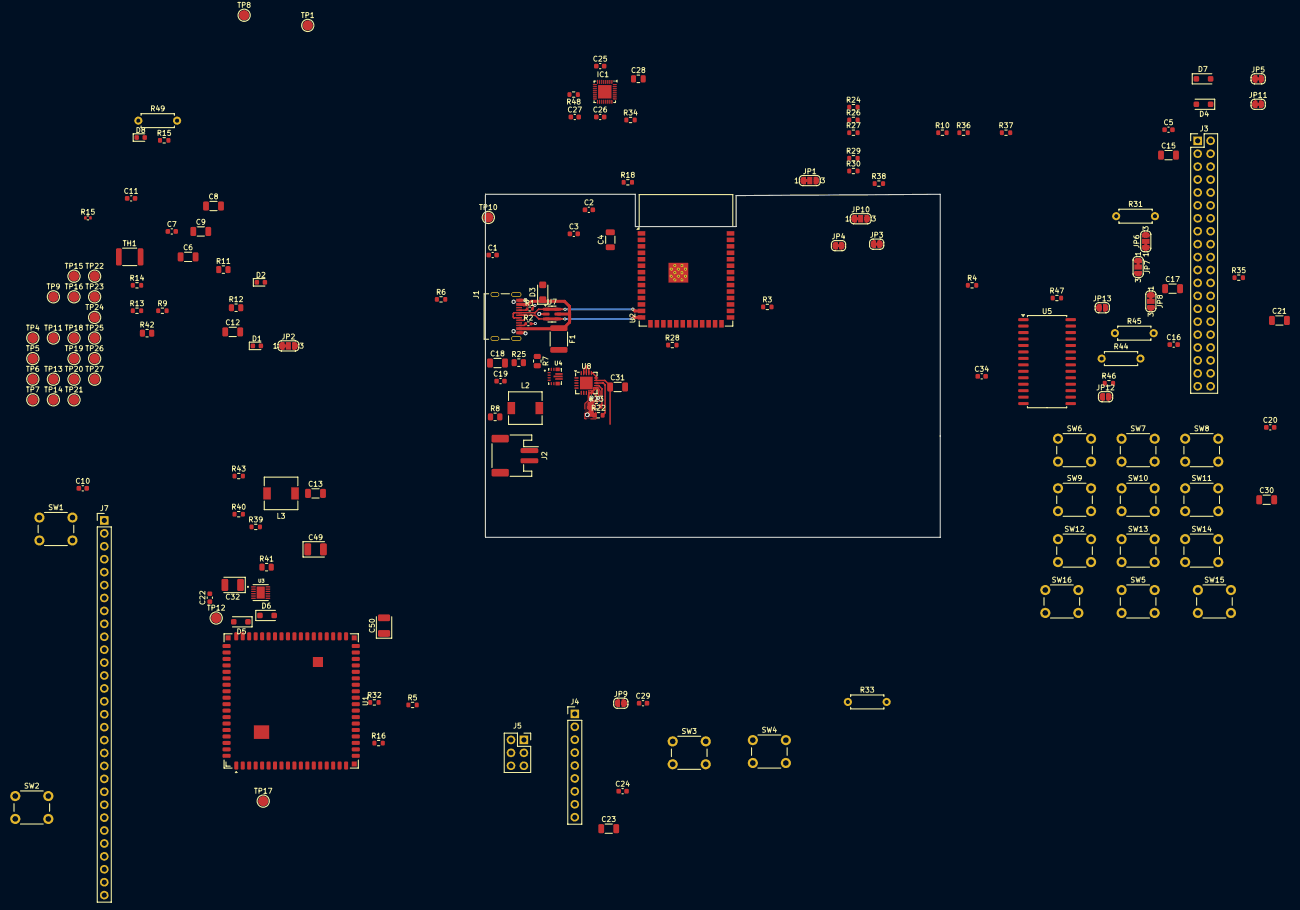
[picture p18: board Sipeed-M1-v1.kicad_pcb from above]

Board: 2 copper layers, 89.4 x 67.4 mm, 160 parts (0 on the bottom side), 134 nets.

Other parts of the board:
R15#2: 10k; R_0402_1005Metric
TP18: TP_ISP_RX_M1; TestPoint_Pad_D2.0mm
TP19: TP_ISP_TX_M1; TestPoint_Pad_D2.0mm

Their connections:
unnamed 134: R15#2.1; also elsewhere on the board
VBUS: R15#2.2; also elsewhere on the board

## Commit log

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2025-09-09 cleared some errors for pcb import from schematic(update pcb)
    [Sipeed-M1-v1.kicad_pcb, Sipeed-M1-v1.kicad_sch]
2025-09-11 Charging IC and USB-C connector review
    Charging IC: fix status LEDs, add LED for power good.
    Charging IC: add optional through-hole resistor to set charging current.
    Charging IC: add thermistor value.
    Remove duplicate 10uF decoupling capacitor.
    VCC pointing up, GND pointing down.
    [Sipeed-M1-v1.kicad_sch]
2025-09-11 Resolved the Errors from the ERC
    Removed several errors at the power lines by defining the ground at
    usbc connector as a power source (place power flag). And second error,
    define pin in BQ symbol from outpoút to poweroutput as it produced a
    error with several output pin connections.
    [Sipeed-M1-v1.kicad_sch]
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2025-09-11 power symbol fix
    [Sipeed-M1-v1.kicad_sch]
2025-09-11 fixing headings
    [Sipeed-M1-v1.kicad_sch]
2025-09-11 tiny layout fixes
    [Sipeed-M1-v1.kicad_sch]
2025-09-12 fixing output of the sipeed M1
    [Sipeed-M1-v1.kicad_sch]
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2025-09-13 updated pcb, added 3v3 and 1v8 net to m1, checked proper deletion of battery prot IC as lipos have their own
    [Sipeed-M1-v1.kicad_pcb, Sipeed-M1-v1.kicad_sch]
2025-09-14 Removed Protection IC from project
    removed battery protection IC BQ29700DSER from our project, as the common lipos have their own anyways onboard.
    updated and removed some other symbols and footprints too (removed the BQ29,
    changed output pin to power output at 3v3 boost conv., removed unused)
    [Sipeed-M1-v1.kicad_pcb, Sipeed-M1-v1.kicad_sch]
2025-09-16 USB-C connector now using SHOU HAN TYPE-C 16PIN 2MD(073)
    Adding footprint and 3D model.
    [Sipeed-M1-v1.kicad_pcb, Sipeed-M1-v1.kicad_sch]
2025-09-16 ESD protection: fix connections, add JLCPCB PN
    [Sipeed-M1-v1.kicad_sch]
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2025-09-17 New FPs for ESP32-S3, R1 and R2. Initial PCB routing.
    Opted for ESP32-S3 with embedded PCB antenna.
    R1 and R2 are now smaller to fit next to USB-C connector.
    [Sipeed-M1-v1.kicad_pcb, Sipeed-M1-v1.kicad_sch]
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2025-09-18 refactor: remove unused footprints
    Also:
    Simplify footprint names.
    Update TROPIC01 datasheet link.
    Clean old symbols from schematic file.
    [cdc-badge.kicad_pcb, cdc-badge.kicad_sch]
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2025-10-09 schematic: USB-C connector peripherals revamp
    Remove PTC. Charging IC has over current protection.
    Add ESD protection to CC lines.
    Add JLCPCB part numbers to resistors.
    Increase resistors size to 0603 (1608m).
    [cdc-badge.kicad_sch]
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2025-10-11 schematic: replace battery charging IC
    From the old and expensive ($3.82) MCP73871 to the new, cheap ($0.98)
    and feature rich BQ25895.
    All components were calculated according to the datasheet and include
    JLCPCB PNs.
    Missing MCU connections, config pins and status LED.
    [cdc-badge.kicad_sch]
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2025-10-12 schematic: fix power symbols and labels
    Use proper power symbols from standard library instead of net labels.
    Create a power net class and add the power nets into it.
    Point all GNDs down.
    Remove redundant capacitors on Rasp Pi header 3.3V pins.
    [cdc-badge.kicad_sch]
2025-10-12 schematic: remove optional 5V sources for M1 and header
    The BQ25895 is able to supply VSYS even when no battery is connected.
    No more need to have the option between VBUS and +5V to power the M1 and
    the Rasp Pi header. The boost converter will always output +5V.
    [cdc-badge.kicad_sch]
2025-10-12 schematic: fix titles
    [cdc-badge.kicad_sch]
2025-10-12 schematic: remove power flags, fix power pin type in symbols
    [cdc-badge.kicad_sch]
2025-10-12 schematic: finish charging IC
    Add MCU connections.
    Connect config pins.
    Add status LED.
    Add power reset button.
    [cdc-badge.kicad_sch]
2025-10-13 schematic: replace 3.3V boost-buck for a simple buck
    Possible because BQ25895 charging IC keeps VSYS over 3.3V.
    Makes things cheaper and simple.
    Document inductor selection.
    Add skeleton of Python script that would calculate the feed forward
    capacitor. Abandoned as we have no proper way to determine the crossover
    frequency.
    [cdc-badge.kicad_sch]
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2025-10-13 schematic: replace 5V boost converter
    Now using the TPS613222A which is a fixed voltage converter and thus
    more simple to use and requiring less passive components.
    It is also cheaper and more available than the PAM2401.
    [cdc-badge.kicad_sch]
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2025-10-14 schematic: remove bulk capacitors from GPIO header
    The Raspberry Pi does not have them. That's responsibility of the HAT.
    [cdc-badge.kicad_sch]
2025-10-14 schematic: review ESP32, RPi header and SAO port
    Use ESP32 symbol from the KiCAD library.
    Disconnect ESP32 pins used by internal PSRAM.
    Fix reset and flash buttons.
    Review all connections from ESP32 to RPi header and SAO port.
    Remove unnecessary solder jumpers and pull up/down resistors.
    Remove bulk capacitors from SAO power output.
    Connect charging IC to ESP32 via I2C.
    Reduce page size from A2 to A3.
    [cdc-badge.kicad_sch]
2025-10-16 schematic: replace TROPIC01 symbol and connecting according to datasheet
    The new symbol by Petr Hodina is much simpler and will much probably be
    merged into the official KiCad library.
    [cdc-badge.kicad_sch]
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2025-10-21 schematic: replace IO expander, use 2x I2C buses
    Replace the expensive MCP23017 IO expander for the cheaper and more
    available TCA9535.
    Add keypad.
    Connect free IOs from MCU and expander to the Rasp Pi header.
    Use 2x I2C buses, one internal, another external.
    Move I2C pull-ups to the MCU.
    Document design choices including I2C pull-up resistors' selection.
    [cdc-badge.kicad_sch]
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2025-10-22 schematic: add LED driver for the e-paper backlight
    Document the design choices.
    [cdc-badge.kicad_sch]
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2025-10-24 Add Grove connector
    Trying the BOOMELE HY-4P connector with a custom footprint.
    [cdc-badge.kicad_sch]
2025-10-25 Add symbols and footprints for battery and display
    With these it's easier to reserve space for them in the PCB.
    Finish RPi header wiring.
    [cdc-badge.kicad_sch]
2025-10-25 schematic: fix ERC errors
    [cdc-badge.kicad_sch]
2025-10-26 schematic: add sliding switches to select CS lines
    Connect all auxiliary signals from display and TROPIC01 to the Rasp Pi
    header.
    [cdc-badge.kicad_sch]
2025-10-26 schematic: test points, remove not needed, add for USB data
    Add ferrite beads to USB power lines to keep EMI out of the cable,
    as per Texas Instruments SPRAAR7A application report.
    [cdc-badge.kicad_sch]
2025-10-26 pcb: importing footprints and initial layout
    Imported https://github.com/EddyBeaupre/KiCad-JLCPCB-Templates for
    multilayer board.
    Imported Rasp Pi layout from KiCad's HAT template.
    [cdc-badge.kicad_pcb]
2025-10-27 schematic: ceetee reviews, secure element
    Add 0 ohm resistor to ease power glitch testing.
    Add pads for pull up on GPO/IRQ, and pull down on CS.
    [cdc-badge.kicad_sch]
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2025-10-27 schematic: ceetee reviews, fix ESP32 bootstrap pins
    IO45 and IO46 must be low during boot. They have internal weak
    pull-downs but were connected to nets with strong pull-ups. Now
    connecting to nets without any resistors.
    [cdc-badge.kicad_sch]
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2025-10-27 schematic: fix ERC errors with exclusions instead of power flags
    Power flags just clog the schematic and add no info.
    Replaced with exclusions with proper comments.
    [cdc-badge.kicad_sch]
2025-10-28 schematic: fix frontlight connector orientation
    The Jushuo connector we are using has its pins numbered in the reverse
    order of the frontlight connector shown on the GDEY029T94-FL03
    datasheet.
    [cdc-badge.kicad_sch]
2025-10-28 edited FP of esp32, screen and batt, rearranged FPs in pcb editor
    [cdc-badge.kicad_pcb]
2025-10-28 schematic: ceetee reviews, e-paper frontlight
    Replace BJT for MOSFET. One less part in BOM.
    [cdc-badge.kicad_sch]
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2025-10-28 schematic: ceetee reviews, fix ESP32 pin assignment
    Move GPCLK to a pin with CLK_OUT support.
    Swap SPI MOSI and MISO.
    [cdc-badge.kicad_sch]
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2025-10-29 schematic: TROPIC01 symbol now adheres to library conventions
    https://klc.kicad.org/symbol/s4/s4.3.html
    As there are decoupling capacitors on each VCC pin they must be
    separated.
    https://klc.kicad.org/symbol/s4/s4.6.html
    Hidden pins contained within the symbol.
    [cdc-badge.kicad_sch]
2025-10-30 schematic: ceetee reviews, Grove connector
    Add selectable output voltage with a switch.
    Add optional pull-ups for I2C.
    [cdc-badge.kicad_sch]
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2025-10-30 schematic: ceetee reviews, replace boost converter
    Now using the TLV61070ADBVR instead of the TPS613222A because it does
    not need an external compensation network.
    [cdc-badge.kicad_sch]
2025-10-30 schematic: ceetee reviews, buck converter
    Use more common resistor values in the voltage divider.
    Add optional feed forward capacitor.
    [cdc-badge.kicad_sch]
2025-10-30 PCB: redesign of 3.3V area, rerouting LED and VSYS area
    [cdc-badge.kicad_pcb]
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2025-10-30 schematic: ceetee reviews, charging IC
    Lower status LED current and connect to stable voltage source.
    Use standard values for config resistors.
    Add pull-downs to OTG and CE to allow hacking.
    Warn about need to set max charge current in firmware.
    [cdc-badge.kicad_sch]
2025-10-31 PCB: Added all the missing caps and resistors to the tropic01
    [cdc-badge.kicad_pcb]
2025-10-31 schematic: ceetee reviews, USB-C connector
    Replace 5V ESD zener diode for 14V TVS, making ESD protection compatible
    with the high voltage input of the charging chip.
    Disconnect VBUS from USBLC6 as it has a breakdown voltage to GND of just
    6V.
    [cdc-badge.kicad_sch]
2025-10-31 PCB: changed pos of TPs, removed TP for 3v and 5v, completed epap components
    [cdc-badge.kicad_pcb, cdc-badge.kicad_sch]
2025-10-31 Schem: Removed TP 3V 5V, PCB: Switched Grove FP to hor., rewiring
    [cdc-badge.kicad_pcb, cdc-badge.kicad_sch]
2025-10-31 PCB: added R46 and R47 to allow hacking via S3 Pins CE and OTG
    [cdc-badge.kicad_pcb]
2025-10-31 schematic: fix Vbus test point location
    [cdc-badge.kicad_sch]
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2025-10-31 PCB: replaced TP for VBUS and Grove switch
    [cdc-badge.kicad_pcb]
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2025-10-31 PCB: Placed Caps for Raspi Header 3.3V and 5V, SAO Port and Grove Caps
    [cdc-badge.kicad_pcb]
2025-10-31 PCB: Reviewed wirings, fixed some errors
    [cdc-badge.kicad_pcb]
2025-10-31 schematic: replace ESD protection on USB data lines
    Now using 2x H3V3U06B instead of the USBLC6-2 chip.
    Smaller, cheaper and not charged loading fees at JLCPCB.
    [cdc-badge.kicad_sch]
2025-11-01 DRU : change dsign rules to make edge clearance from 0.2 to 0.3mm
2025-11-01 schematic: replace display connector for one with top contacts
    [cdc-badge.kicad_sch]
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2025-11-01 schematic: use horizontal Grove connector
    Add the necessary footprint.
    Fix pin numbering.
    Fix silkscreen to pads clearance on other footprints.
    [cdc-badge.kicad_sch]
2025-11-02 schematic: ceetee reviews, remove ferrite bead from GND
    "In most cases the ferrite bead will not have any measurable effect.
    In some it makes it worse, and in very few it is helpful."
    -- ceetee
    [cdc-badge.kicad_sch]
2025-11-02 schematic: ceetee reviews, remove test points from USB data lines
    If probing is needed we can solder wires to the ESD diodes.
    [cdc-badge.kicad_sch]
2025-11-02 schematic: ceetee reviews, Grove voltage selector
    Use solder jumper instead of switch. Switch could lead to accidental
    burning of add-ons. There are very few using 5V exclusively anyway.
    [cdc-badge.kicad_sch]
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2025-11-02 schematic: ceetee reviews, e-paper display power converter
    Relocate negative voltage output capacitor for better readability.
    [cdc-badge.kicad_sch]
2025-11-02 PCB: Erased all Components and tracks for full redesign
    [cdc-badge.kicad_pcb]
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2025-11-02 schematic: ceetee reviews, bottom entry for SAO
    Trying a part out of JLCPCB that may not work.
    [cdc-badge.kicad_sch]
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2025-11-03 pcb: set default widths and clearances, try copper pours
    Defaults set for both tracks and vias.
    [cdc-badge.kicad_pcb]
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2025-11-04 schematic: place TROPIC01 pull-ups outside the glitching path
    [cdc-badge.kicad_sch]
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2025-11-05 PCB: 3.3V buck conv. design, rst and flash button, routing optimize
    Made a design draft how to place key parts for 3.3V generating unit,
    completely rearrange the position and wiring of the reset and flash btn,
    grouped them together with the programmable LED (2) and optimized
    the routing for various tracks f.e. SAO connections and SPI CS switches.
    Extended the pour arreas to the SAO port, optimized various vias
    related to ESP32 S3.
    [cdc-badge.kicad_pcb]
2025-11-05 Changed Custom Rules and Board Constraints
    Board Setup: Changed Copper annual width constraints of PTH from 0.15 to 0.075,
    had to adjust custom rule to differentiate: THT Pads stay at 0.15, vias min is 0.075mm.
    PCB: moved some vias, that are too close to each other or to a pad/track.
    [cdc-badge.kicad_pcb]
2025-11-05 PCB: move some other vias and tracks at USB-conn to resolve EDC errors
    [cdc-badge.kicad_pcb]
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2025-11-05 FP: Edited footprint of USBc conn. to resolve EDC errors
    Changed following in (project lib) footprint:
    -made GND pads (most outer pinpads) slightly smaller (-0.026mm) to resolve clearance
    to round holes EDC errors. Only cut the side to the holes (inner side).
    -made outher (oval) mount hole pads (only the surrounding pads, not the holes itselves)
    slightly larger, so that formula Pads dia. - Hole dia. / 2 = 0.15mm min.!
    Had to add +0.003mm to pad length, width stayed the same.
    - changed general FP-Type to THT (was SMD) to resolve EDC error
    (EDC accepts THT also if some parts as pinpads are type SMD, but not general type to be
    SMD, if some parts are obviously THT like the mountholes.
    -erased si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
    [cdc-badge.kicad_pcb]
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2025-11-06 PCB: zones extended, rerouting and placement of critical components
    -expanded zones/pours to the SAO connector region
    -placed caps to to switches, SAO, Grove and display region
    -(re)routing SPI connections between S3 and display connector
    -finish replacement/arrangement of display components
    [cdc-badge.kicad_pcb]
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2025-11-09 PCB: rerouting and replacement
    -rerouting of bat+ track to clear area round raspi-header mounthole
    -rerouting of the SPI connection to optimize routes
    -moving the 5V system 1mm away from charging IC to separate inductors
    [cdc-badge.kicad_pcb]
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2025-11-09 Edge-Track clearance increased, glitch resistor edited
    -Custom Rules: increased edge-to-track clearance to min. 0.5mm
    -Schem: set R41 (tropic01 glitching location) to DNP and connect
    the path (to be scratched there)
    -Schem: relink inverted (flipped) battery FP to battery symbol
    -PCB: updated the pcb from schem, including bat FP
    [cdc-badge.kicad_pcb, cdc-badge.kicad_sch]
2025-11-10 Various changes on the PCB
    PCB:
    -Grove Voltage select label
    -increased distance between Display-SPI vias and moved them to the right of the connector
    -moved caps and res to the right side of the associated buttons (keypad)
    -connect all the buttons and other connections to the expander
    -positioned CS switches and their pullups, partially labeled them
    -routing all raspi connections
    -rearranged tropic01 components and created no-fill zone to ensure glitching possib.
    [cdc-badge.kicad_pcb, cdc-badge.kicad_sch]
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2025-11-10 Multiple changes to complete the PCB design
    -Custom Design Rules: Hole to Hole Clearance diff. net: min 0.2mm
    -connect all remaining unconnected pins
    -rearranged position of R44, R45 and R49
    -connecting tropic01 and its components to the corresponding pins/tracks
    -configure keepout area 3V3 around tropics01 to enable glitching capability
    -routing 5V tracks to the connectors
    -routing the USB-Dataline with new distance between tracks: 0.125mm
    -placing many 3V3 vias to reach secluded areas
    -resolved all remaining EDC errors
    [cdc-badge.kicad_pcb]
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2025-11-12 font and pour
    -replaced the font of the labels to a free one
    -reshaped the copper pour at front and back around the SAO port
    [cdc-badge.kicad_pcb]
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2025-11-12 pcb: parasew reviews, fix silkscreen graphics and text
    [cdc-badge.kicad_pcb]
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2025-11-13 Grove connector: new MPN to work with NextPCB
    Fix datasheet links in BOOMELE footprints.
    [cdc-badge.kicad_pcb, cdc-badge.kicad_sch]
2025-11-14 schematic: fix, battery connector was not in BOM
    [cdc-badge.kicad_pcb, cdc-badge.kicad_sch]
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2025-11-14 pcb: fix silkscreen
    Make sure silkscreen is not on top of vias.
    Show missing designators.
    [cdc-badge.kicad_pcb]
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2025-11-14 pcb: fix stackup layer thicknesses
    According to JLC04161H-7628 stackup.
    https://jlcpcb.com/impedance
    Use ENIG as copper finish for some nice PCB art in the future.
    [cdc-badge.kicad_pcb]
2025-11-14 pcb: fix misplaced vias and DRC errors about annular size
    Moved BQ25895 GND vias a bit more inward.
    [cdc-badge.kicad_pcb]
2025-11-14 pcb: fix footprint related DRC warnings
    [cdc-badge.kicad_pcb]
2025-11-14 pcb: fix silkscreen DRC warnings
    Replace text chevron in our footprints for a triangle.
    [cdc-badge.kicad_pcb]
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2025-11-16 pcb: test points, vias, islands
    Test points are now SMD again for better aesthetics.
    Review via placement.
    Fix islands.
    Fix silkscreen to via overlap.
    [cdc-badge.kicad_pcb, cdc-badge.kicad_sch]
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2025-11-20 panelization: do not pour copper in the rails
    Avoids DRC errors between fiducials and pour.
2025-11-23 DFM: fix JLCPCB soldermask constraints
    [cdc-badge.kicad_pcb]
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2025-11-23 pcb: fix clearances of USB D- via
    Accommodates for the new track width and spacing.
    [cdc-badge.kicad_pcb]
2025-11-24 pcb: increase general clearance to 0.127 mm (5 mil)
    Makes PCB cheaper to produce in multiple fabs.
    [cdc-badge.kicad_pcb]
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2025-11-24 schematic: add mounting pins to battery connector
    Fixes liking with PCB.
    Remove non-generic fields from symbols.
    [cdc-badge.kicad_sch]
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2025-11-27 footprints: fix SOD-123FL, add datasheets to descriptions
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2025-12-03 footprints: fix silkscreen text thickness
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2025-12-09 pcb: enlarge flex cable cut-out by 3mm down
    [cdc-badge.kicad_pcb]
2025-12-09 pcb: make outer edges of flex cable slit rounder
    [cdc-badge.kicad_pcb]
2025-12-09 Do not populate SAO but add pads for it on both sides.
    The HC-PM254-8.5H-2x3PS part does not work for bottom entry.
    Opting to leave the pads unpopulated and solder the 610006243021 from
    Würth Elektronik by hand.
    [cdc-badge.kicad_pcb, cdc-badge.kicad_sch]
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2025-12-10 pcb fix: kikit fabrication output cannot handle multiline knockouts
    [cdc-badge.kicad_pcb]
2025-12-29 Add .step file of case
    Case clips onto the back of the PCB. Fit is close, so make sure your printer can meet tolerances or add an outer wall offset. Printing in PETG is recommended for semi flexible retention clips. PLA works, but clips can break if you are not careful.
    [CDC_badge_case_v1.1.step]
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2026-01-11 Push buttons with larger keycap
    Replace the TS-1088-AR02016 for the TS114516025 (ALPS TS114516025 clone).
    These have a larger keycap which is much easier to press and there are
    many clones in the market.
    Footprints: round pad edges according to KiCad Library Conventions.
    [cdc-badge.kicad_pcb, cdc-badge.kicad_sch]
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2026-02-11 cases: v1.1 files to address button height difference
    Explain in the detail in the cases README.
    Addresses GitHub issue #2.
    [all.FCStd, back.step, front.step]
2026-02-12 Update README.md
    changed broken ALPS button data sheet link to product page of buttons
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2026-02-15 Improve case by ct with better tolerances
    - improved alignment between case and SMD buttons on PCB
    - variant for 1.1 has shorter stems and is otherwise identical
    - added images for reference
    [back.step]
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

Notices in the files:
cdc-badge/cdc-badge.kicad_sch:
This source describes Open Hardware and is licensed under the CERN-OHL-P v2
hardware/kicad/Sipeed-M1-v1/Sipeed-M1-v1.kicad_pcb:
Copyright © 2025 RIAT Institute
